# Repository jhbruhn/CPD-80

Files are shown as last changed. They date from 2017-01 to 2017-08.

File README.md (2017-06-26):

# Crazy Programmable Device (CPD)

## (Planned) Features

* 6MHz Z80 Processor
* UART Serial Communication
* 64k RAM
* 32k ROM
* CF Card Support (FAT16 or FAT12)

## Memory layout:
| Address | Type |
| --- | --- |
| 0x0000-0x7FFF | ROM / RAM  |
| 0x8000-0xFFFF | RAM  |

## IO

| A11| A10| A9 | A8 | Device |
| ---|----|----|----|---|
| 0  | 0  | 0  | 0  | IDE Port (CF Card) |
| 0  | 0  | 0  | 1  | UART (16550) |
| 0  | 0  | 1  | 0  | PS/2 Keyboard |
| 0  | 0  | 1  | 1  | RTC-72421 |
| 0  | 1  | 0  | 0  | MemoryBank (write 0 for ROM and 2 for RAM in first 32k) |
| 0  | 1  | 0  | 1  | Video (TMS9918) |
| 0  | 1  | 1  | 0  | Audio (AY-3-8910A) |

To Address device 0:

B = 0

OUT (C), d

To Address device 1:

B = 1

OUT (C), d

etc...

sdcc:
__banked __ad(0x16c) int pedabaumert oder so

##Future:
Video Card with TMS9918. Also PS/2 keyboard input (or something similar). Real time Clock?

## Boot:
* start at 0x0000.
* load Bootsector from CF card to 0x8000, or into BANK RAM at 0x0000.
* jump to 0x8000 (0x0000)
* Bootsector loads FAT files, executes KERNEL.ULF or something like that. Autoexec.

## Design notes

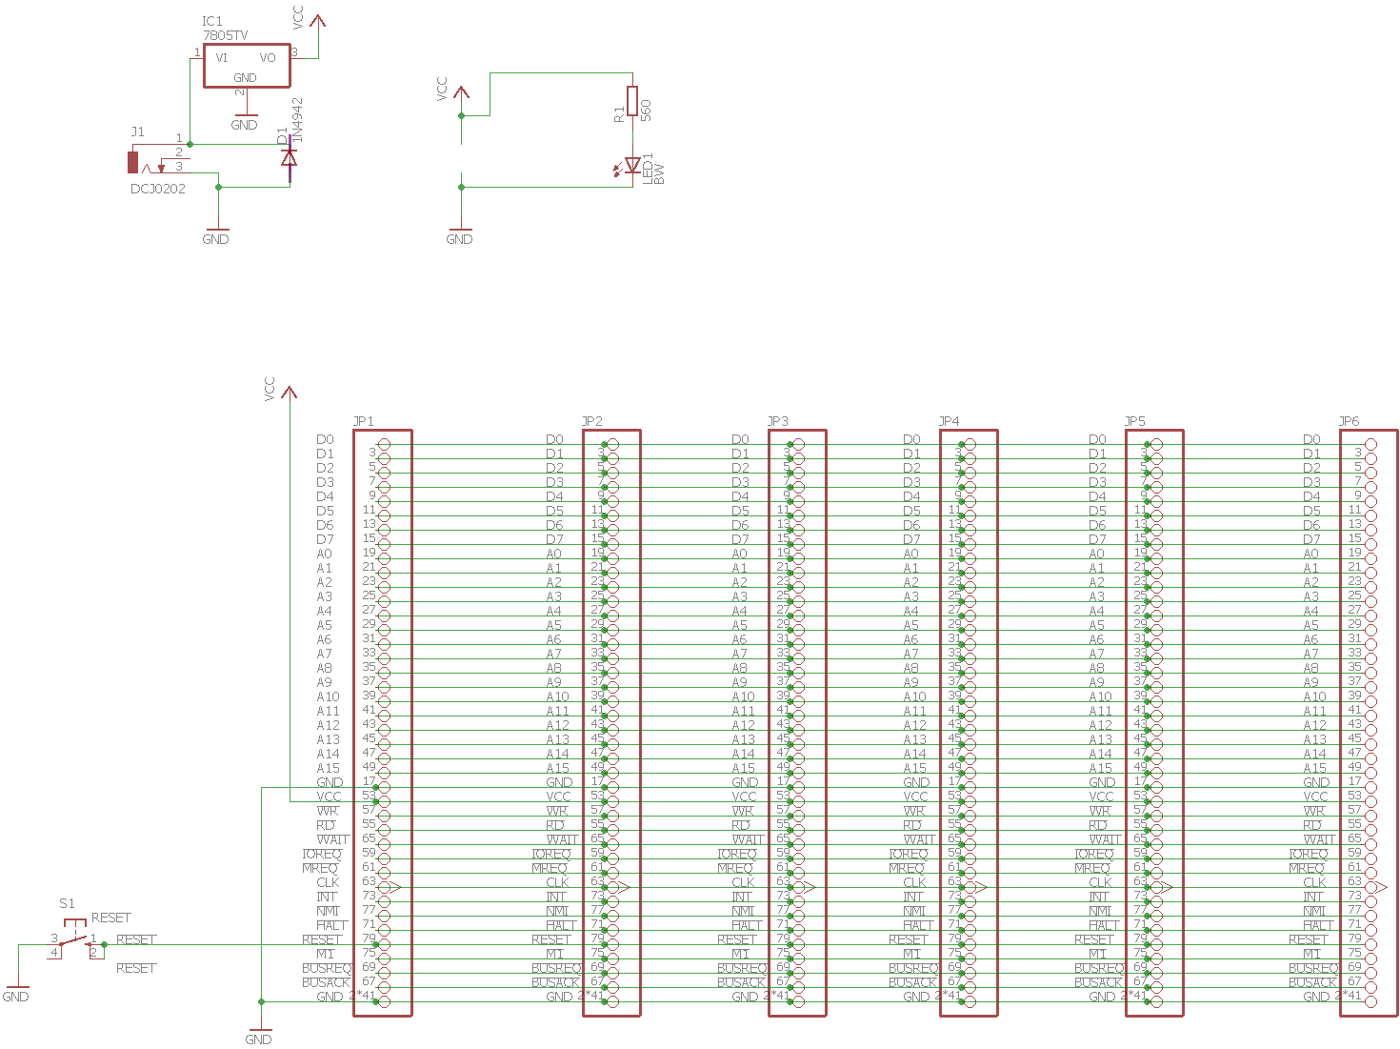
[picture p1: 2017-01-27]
pictures/muddi.png

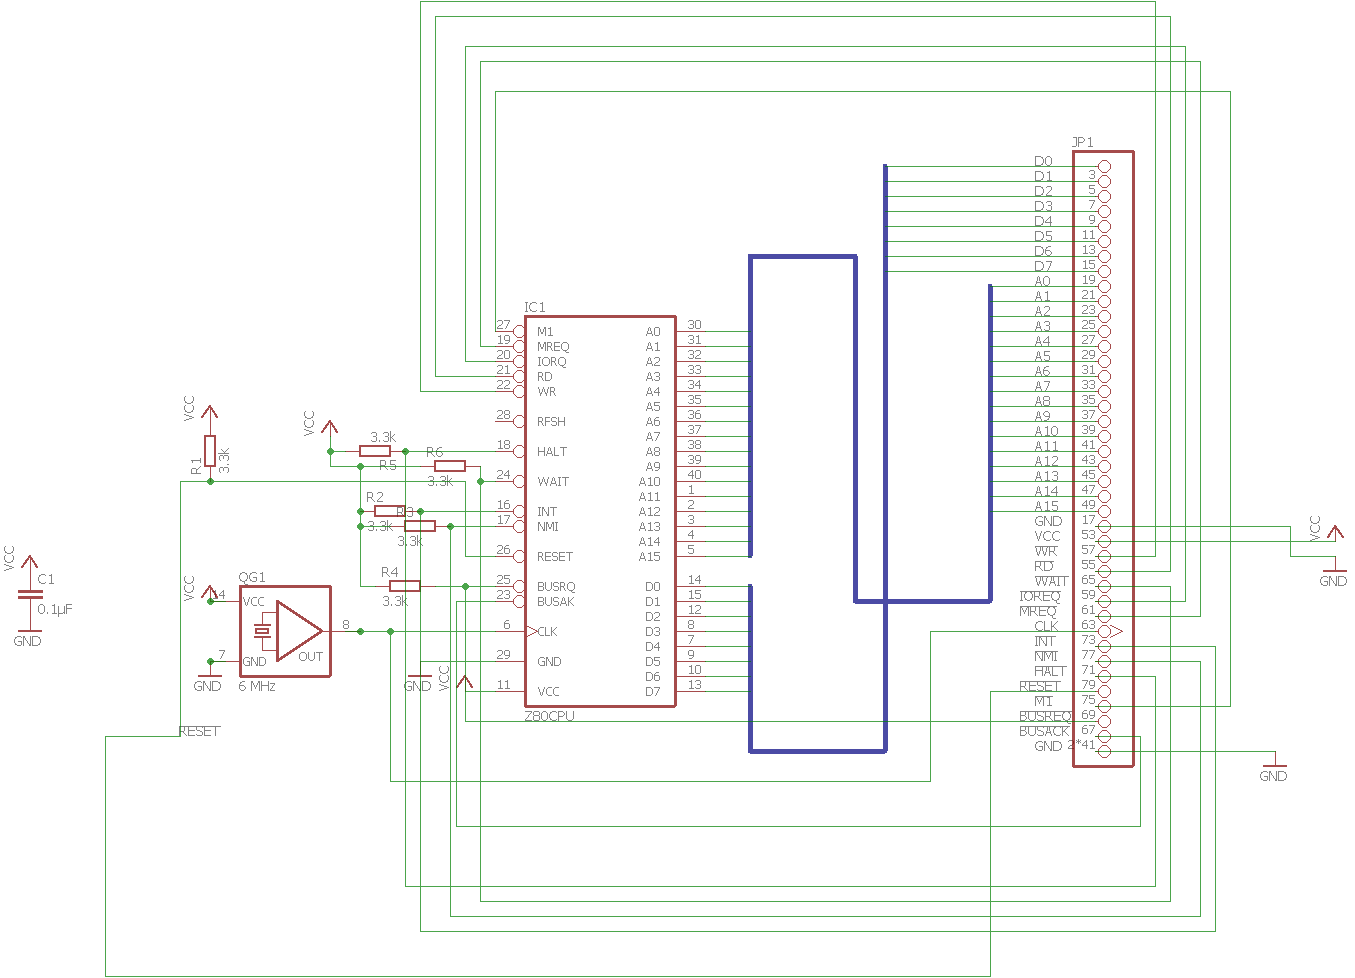
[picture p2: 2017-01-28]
pictures/cpu.png

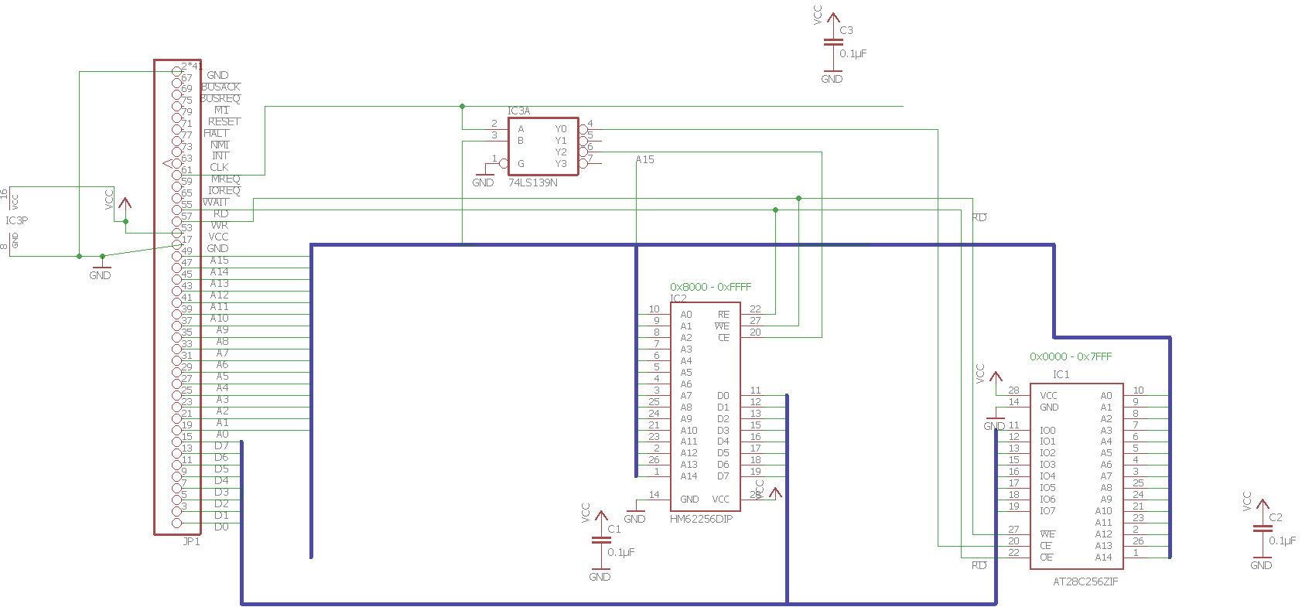
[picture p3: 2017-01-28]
pictures/memory.png

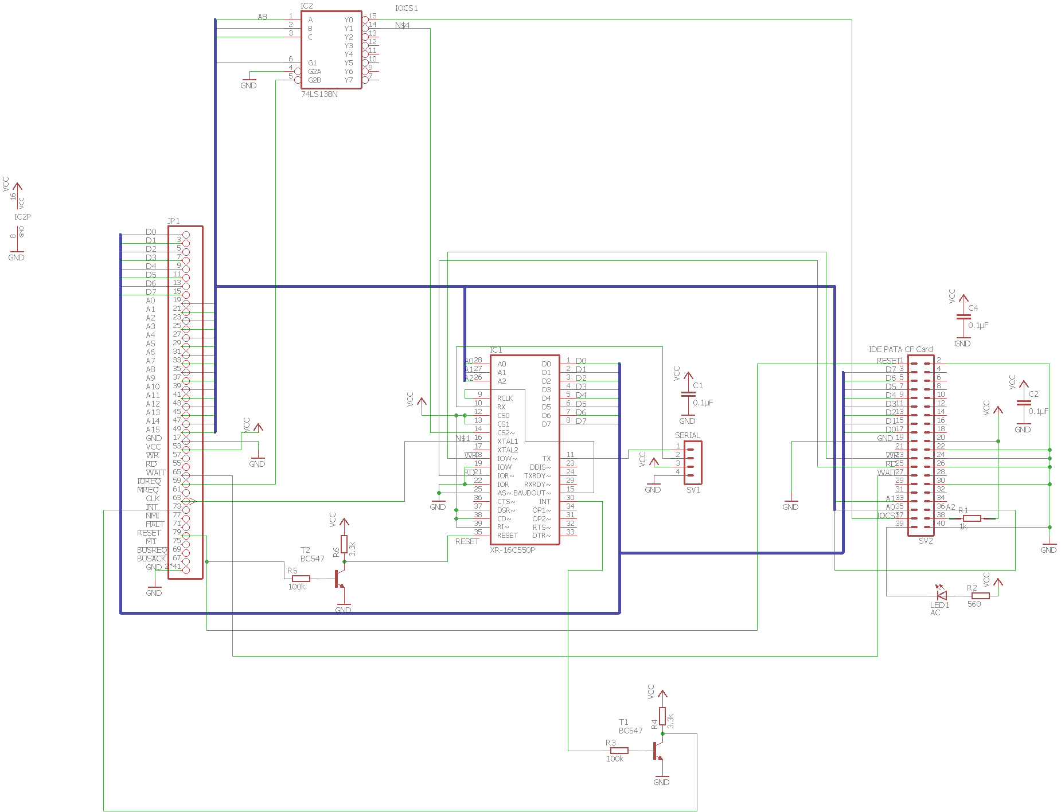
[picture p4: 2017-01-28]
pictures/serialcf.png

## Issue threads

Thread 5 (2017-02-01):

Fix Protection Diode

jhbruhn, 2017-02-01:

Closed 2017-02-01.

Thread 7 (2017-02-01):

Add Oscillator to Serial Board

jhbruhn, 2017-02-01:

Closed 2017-02-02.

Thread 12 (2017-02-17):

Missing VCC/GND Connections

jhbruhn, 2017-02-17:
CPU:
* C1 left to VCC
Memory:
* IC 3 GND (upper left), VCC
* V1 VCC (10)
* C5 VCC (left)
* C6 VCC and GND
SerialCF:
* R1 left to VCC (16c550)
* C4 left to R6 left (VCC)

jhbruhn, 2017-03-03:
Memory
* V2 pin 6 connect to VCC

CFSerial
* IC2 pin 6 connect to VCC

jhbruhn, 2017-06-26:
CPU:
Pin 24 to Wait Resistor
Pin 17 to NMI Resistor
Pin 16 to INT Resistor

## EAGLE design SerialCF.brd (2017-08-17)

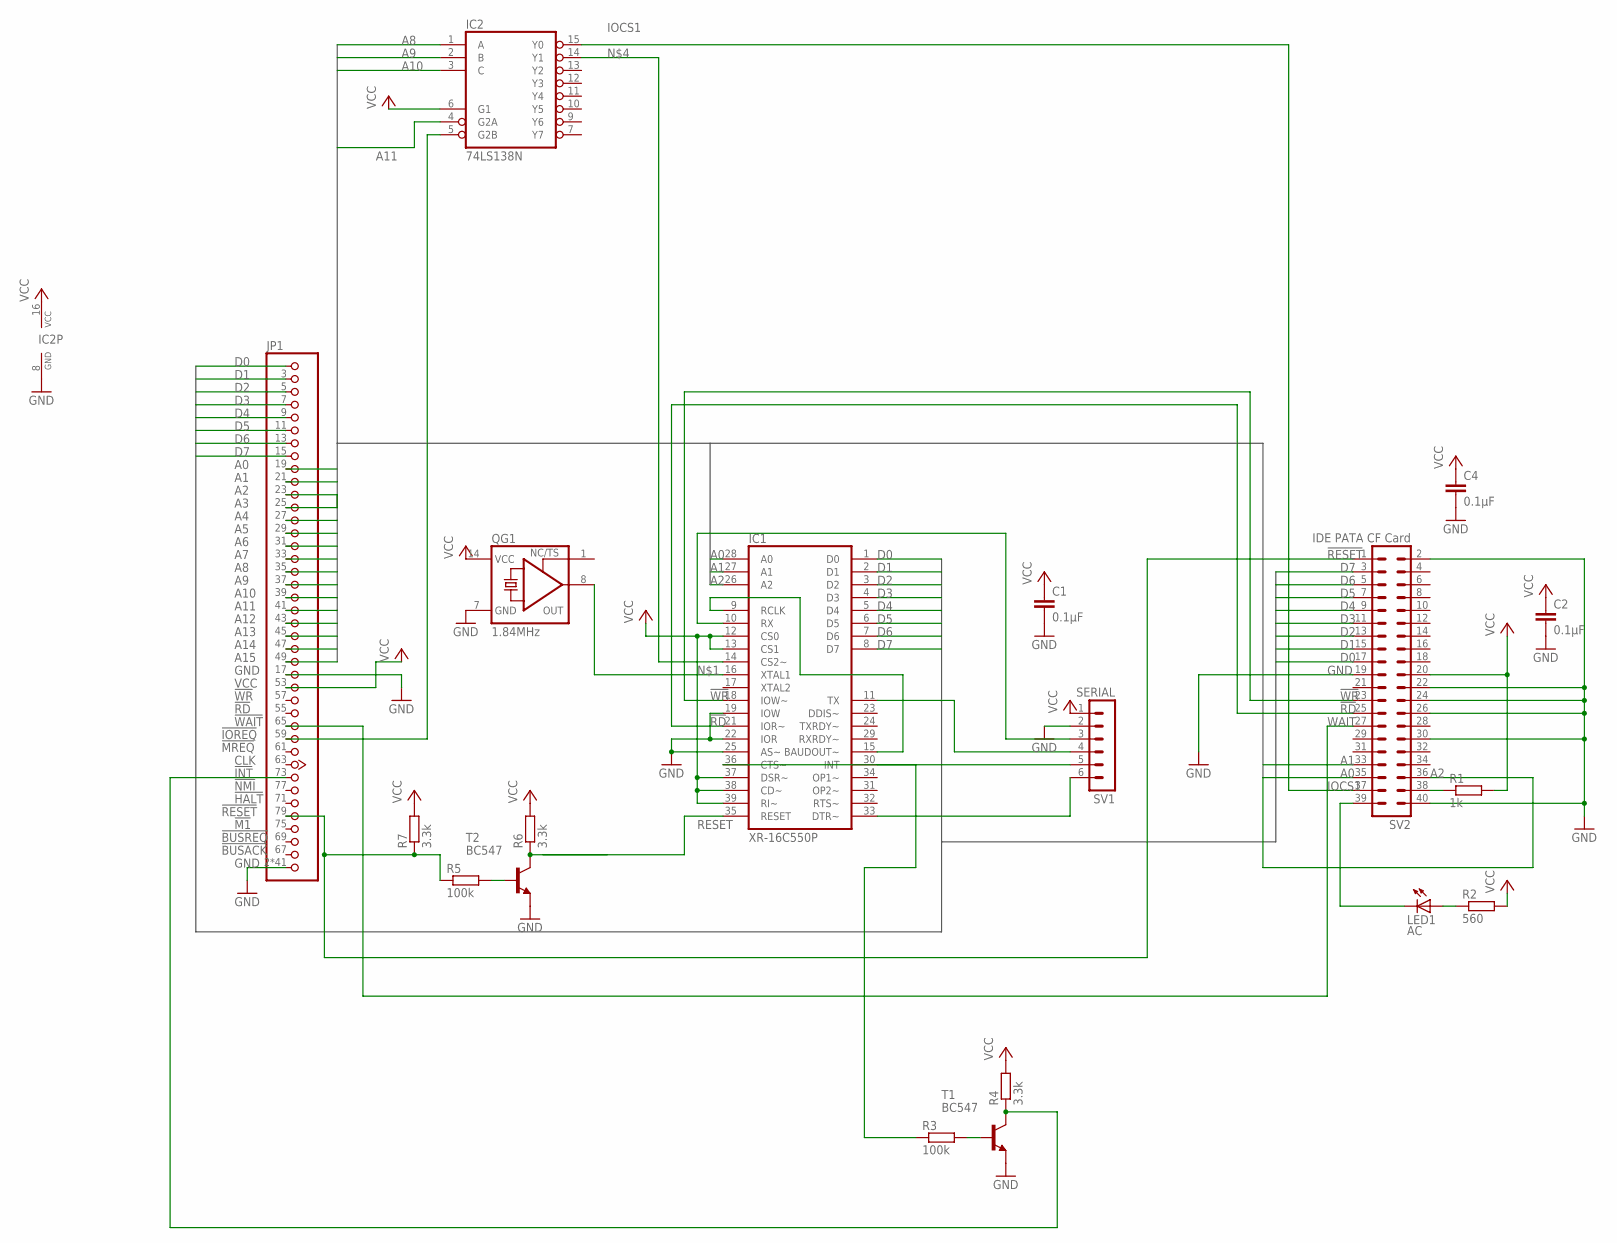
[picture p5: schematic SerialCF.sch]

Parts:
C1, C2, C4: 0.1µF; C5B2.5
IC1: XR-16C550P; DIL40
IC2: 74LS138N; DIL16
JP1: JEANNECTOR/90; 2X25/90
LED1: AC; LED5MM
QG1: 1.84MHz; DIL14S
R1: 1k; 0207/10; MPN MCRE000037
R2: 560; 0204/7
R3, R5: 100k; 0207/2V
R4, R6, R7: 3.3k; 0207/2V
SV1: SERIAL; MA06-1
SV2: IDE PATA CF Card; MA20-2
T1, T2: BC547; TO92

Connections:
!RD: IC1.21 (IOR~), SV2.25
!RESET: JP1.79 (!RESET), R7.1, SV2.1
!WR: IC1.18 (IOW~), SV2.23
A0: IC1.28 (A0), JP1.19 (A0), SV2.35
A1: IC1.27 (A1), JP1.21 (A1), SV2.33
A2: IC1.26 (A2), JP1.23 (A2), SV2.36
A3: JP1.25 (A3)
A4: JP1.27 (A4)
A5: JP1.29 (A5)
A6: JP1.31 (A6)
A7: JP1.33 (A7)
A8: IC2.1 (A), JP1.35 (A8)
A9: IC2.2 (B), JP1.37 (A9)
A10: IC2.3 (C), JP1.39 (A10)
A11: IC2.4 (G2A), JP1.41 (A11)
A12: JP1.43 (A12)
A13: JP1.45 (A13)
A14: JP1.47 (A14)
A15: JP1.49 (A15)
D0: IC1.1 (D0), JP1.1 (D0), SV2.17
D1: IC1.2 (D1), JP1.3 (D1), SV2.15
D2: IC1.3 (D2), JP1.5 (D2), SV2.13
D3: IC1.4 (D3), JP1.7 (D3), SV2.11
D4: IC1.5 (D4), JP1.9 (D4), SV2.9
D5: IC1.6 (D5), JP1.11 (D5), SV2.7
D6: IC1.7 (D6), JP1.13 (D6), SV2.5
D7: IC1.8 (D7), JP1.15 (D7), SV2.3
GND: C1.2, C2.2, C4.2, IC1.19 (IOW), IC1.20 (GND), IC1.22 (IOR), IC1.25 (AS~), IC2.8 (GND), JP1.2 (GND), JP1.4 (GND), JP1.6 (GND), JP1.8 (GND), JP1.10 (GND), JP1.12 (GND), JP1.14 (GND), JP1.16 (GND), JP1.17 (GND), JP1.18 (GND), JP1.20 (GND), JP1.22 (GND), JP1.24 (GND), JP1.26 (GND), JP1.28 (GND), JP1.30 (GND), JP1.32 (GND), JP1.34 (GND), JP1.36 (GND), JP1.38 (GND), JP1.40 (GND), JP1.42 (GND), JP1.44 (GND), JP1.46 (GND), JP1.48 (GND), JP1.50 (GND), JP1.51 (GND), JP1.52 (GND), JP1.54 (GND), JP1.56 (GND), JP1.58 (GND), JP1.60 (GND), JP1.62 (GND), JP1.64 (GND), JP1.66 (GND), JP1.68 (GND), JP1.70 (GND), JP1.72 (GND), JP1.74 (GND), JP1.76 (GND), JP1.78 (GND), JP1.80 (GND), QG1.7 (GND), SV1.2, SV2.2, SV2.19, SV2.22, SV2.24, SV2.26, SV2.30, SV2.40, T1.1 (E), T2.1 (E)
IOCS1: IC2.15 (Y0), SV2.37
unnamed: IC1.16 (XTAL1), QG1.8 (OUT)
unnamed: LED1.K (C), SV2.39
unnamed: LED1.A, R2.1
unnamed: IC1.14 (CS2~), IC2.14 (Y1)
unnamed: IC2.5 (G2B), JP1.59 (!IOREQ)
unnamed: R5.2, T2.2 (B)
unnamed: R6.1, T2.3 (C)
unnamed: R3.2, T1.2 (B)
unnamed: JP1.73 (!INT), R4.1, T1.3 (C)
unnamed: IC1.30 (INT), R3.1
unnamed: IC1.11 (TX), SV1.4
unnamed: IC1.36 (CTS~), SV1.5
unnamed: IC1.9 (RCLK), IC1.15 (BAUDOUT~)
unnamed: IC1.33 (DTR~), SV1.6
unnamed: IC1.10 (RX), SV1.3
unnamed: R1.1, SV2.38
RESET: IC1.35 (RESET)
VCC: C1.1, C2.1, C4.1, IC1.12 (CS0), IC1.13 (CS1), IC1.37 (DSR~), IC1.38 (CD~), IC1.39 (RI~), IC1.40 (VCC), IC2.6 (G1), IC2.16 (VCC), JP1.53 (VCC), QG1.14 (VCC), R1.2, R2.2, R4.2, R6.2, R7.2, SV1.1, SV2.20
WAIT: JP1.65 (!WAIT), SV2.27

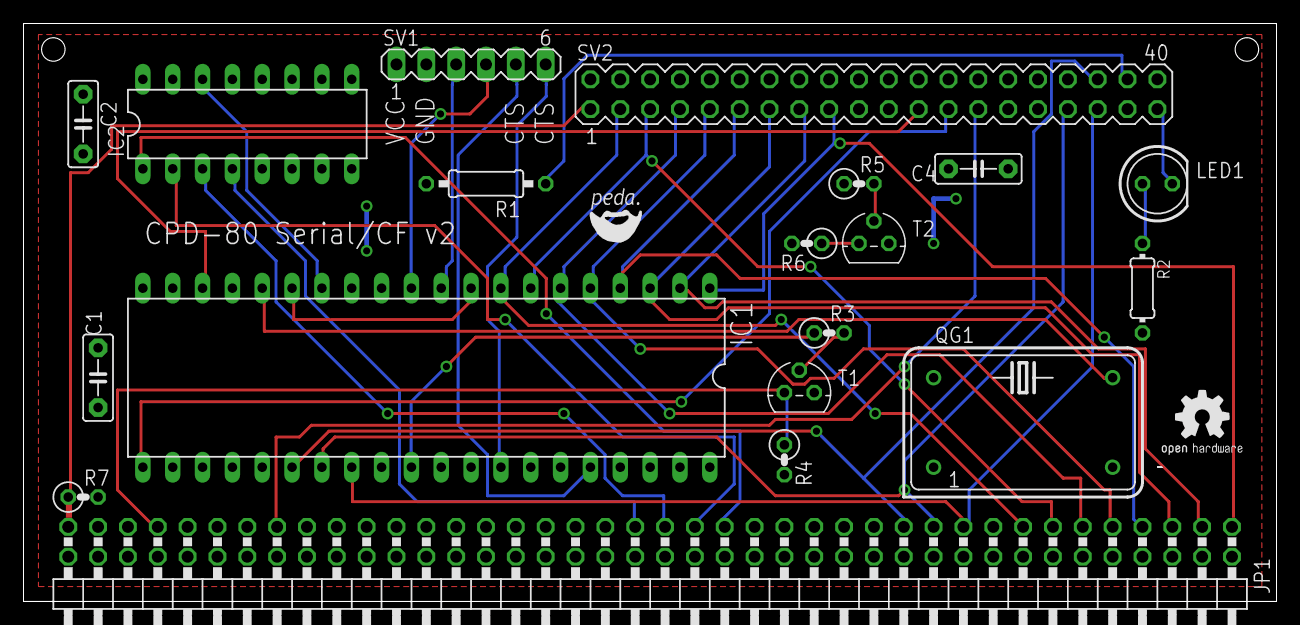
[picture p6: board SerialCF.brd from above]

Board: 2 copper layers, 106.7 x 49.2 mm, 20 parts (0 on the bottom side), 38 nets.

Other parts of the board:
U$1: OSHW2

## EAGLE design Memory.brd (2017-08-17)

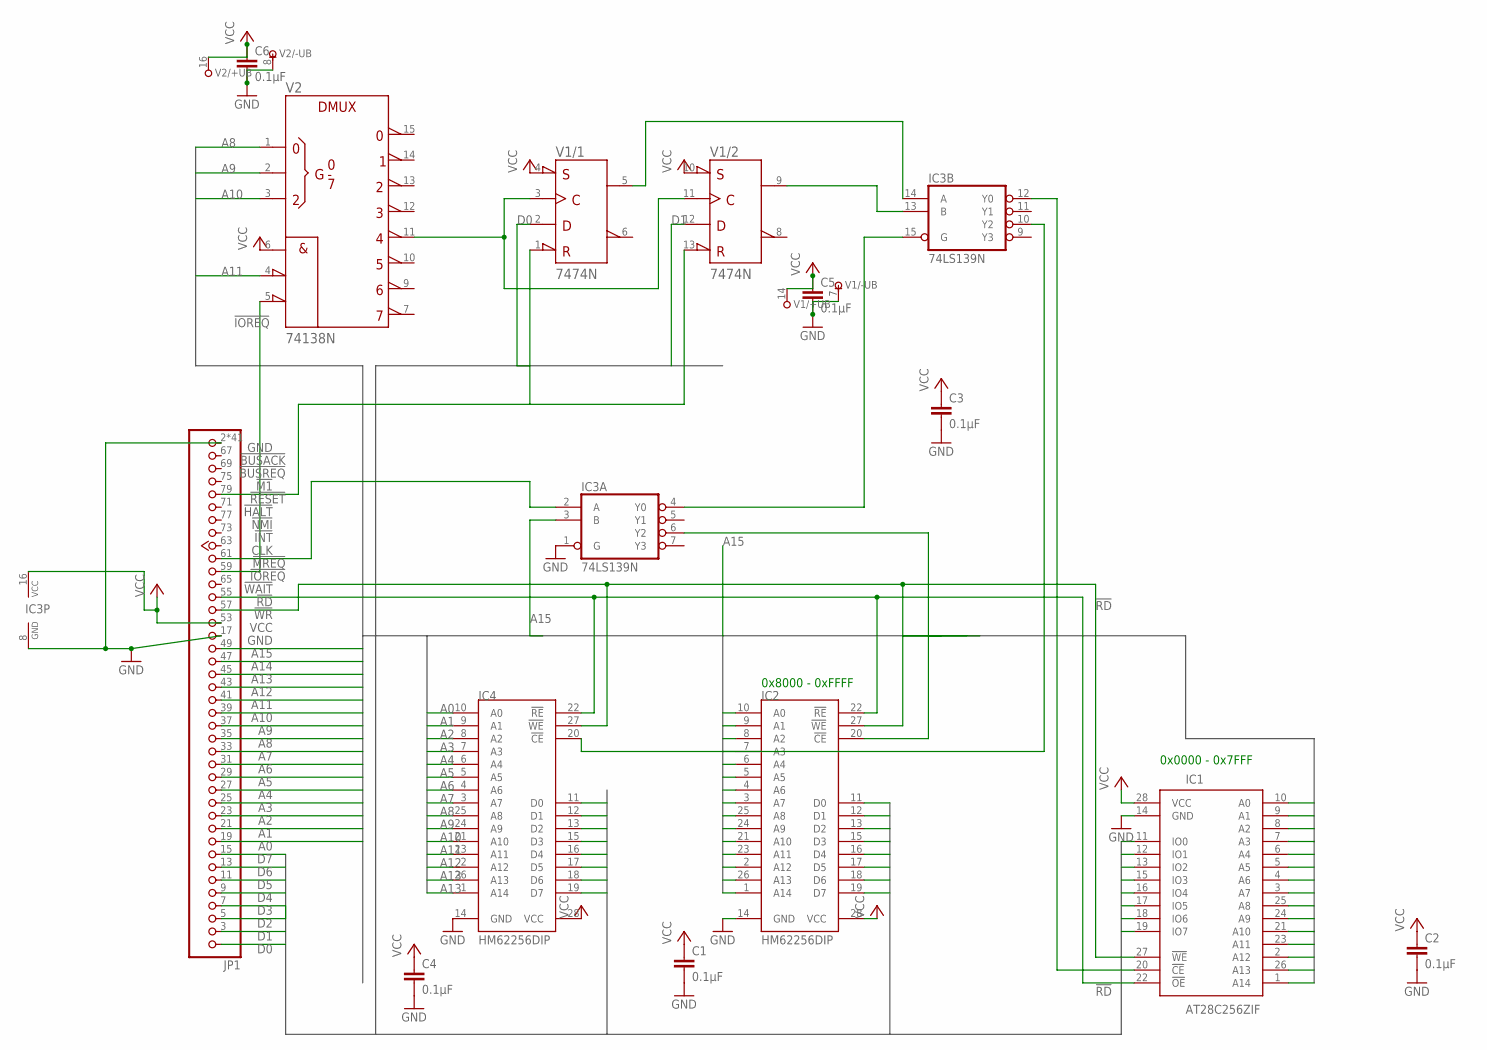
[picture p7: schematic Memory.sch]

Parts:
C1, C2, C3, C4, C5, C6: 0.1µF; C5B2.5
IC1: AT28C256ZIF; DIL28-ZIF
IC2, IC4: HM62256DIP; HM62256-DIP
IC3: 74LS139N; DIL16
JP1: JEANNECTOR/90; 2X25/90
V1: 7474N; DIL14
V2: 74138N; DIL16

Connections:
!IOREQ: JP1.59 (!IOREQ), V2.5 (!G2B)
!MREQ: IC3.2 (A), JP1.61 (!MREQ)
!RD: IC1.22 (!OE), IC2.22 (!RE), IC4.22 (!RE), JP1.55 (!RD)
!WR: IC1.27 (!WE), IC2.27 (!WE), IC4.27 (!WE), JP1.57 (!WR)
A0: IC1.10 (A0), IC2.10 (A0), IC4.10 (A0), JP1.19 (A0)
A1: IC1.9 (A1), IC2.9 (A1), IC4.9 (A1), JP1.21 (A1)
A2: IC1.8 (A2), IC2.8 (A2), IC4.8 (A2), JP1.23 (A2)
A3: IC1.7 (A3), IC2.7 (A3), IC4.7 (A3), JP1.25 (A3)
A4: IC1.6 (A4), IC2.6 (A4), IC4.6 (A4), JP1.27 (A4)
A5: IC1.5 (A5), IC2.5 (A5), IC4.5 (A5), JP1.29 (A5)
A6: IC1.4 (A6), IC2.4 (A6), IC4.4 (A6), JP1.31 (A6)
A7: IC1.3 (A7), IC2.3 (A7), IC4.3 (A7), JP1.33 (A7)
A8: IC1.25 (A8), IC2.25 (A8), IC4.25 (A8), JP1.35 (A8), V2.1 (A)
A9: IC1.24 (A9), IC2.24 (A9), IC4.24 (A9), JP1.37 (A9), V2.2 (B)
A10: IC1.21 (A10), IC2.21 (A10), IC4.21 (A10), JP1.39 (A10), V2.3 (C)
A11: IC1.23 (A11), IC2.23 (A11), IC4.23 (A11), JP1.41 (A11), V2.4 (!G2A)
A12: IC1.2 (A12), IC2.2 (A12), IC4.2 (A12), JP1.43 (A12)
A13: IC1.26 (A13), IC2.26 (A13), IC4.26 (A13), JP1.45 (A13)
A14: IC1.1 (A14), IC2.1 (A14), IC4.1 (A14), JP1.47 (A14)
A15: IC3.3 (B), JP1.49 (A15)
D0: IC1.11 (IO0), IC2.11 (D0), IC4.11 (D0), JP1.1 (D0), V1.2 (D)
D1: IC1.12 (IO1), IC2.12 (D1), IC4.12 (D1), JP1.3 (D1), V1.12 (D)
D2: IC1.13 (IO2), IC2.13 (D2), IC4.13 (D2), JP1.5 (D2)
D3: IC1.15 (IO3), IC2.15 (D3), IC4.15 (D3), JP1.7 (D3)
D4: IC1.16 (IO4), IC2.16 (D4), IC4.16 (D4), JP1.9 (D4)
D5: IC1.17 (IO5), IC2.17 (D5), IC4.17 (D5), JP1.11 (D5)
D6: IC1.18 (IO6), IC2.18 (D6), IC4.18 (D6), JP1.13 (D6)
D7: IC1.19 (IO7), IC2.19 (D7), IC4.19 (D7), JP1.15 (D7)
GND: C1.2, C2.2, C3.2, C4.2, C5.2, C6.2, IC1.14 (GND), IC2.14 (GND), IC3.1 (G), IC3.8 (GND), IC4.14 (GND), JP1.2 (GND), JP1.4 (GND), JP1.6 (GND), JP1.8 (GND), JP1.10 (GND), JP1.12 (GND), JP1.14 (GND), JP1.16 (GND), JP1.17 (GND), JP1.18 (GND), JP1.20 (GND), JP1.22 (GND), JP1.24 (GND), JP1.26 (GND), JP1.28 (GND), JP1.30 (GND), JP1.32 (GND), JP1.34 (GND), JP1.36 (GND), JP1.38 (GND), JP1.40 (GND), JP1.42 (GND), JP1.44 (GND), JP1.46 (GND), JP1.48 (GND), JP1.50 (GND), JP1.51 (GND), JP1.52 (GND), JP1.54 (GND), JP1.56 (GND), JP1.58 (GND), JP1.60 (GND), JP1.62 (GND), JP1.64 (GND), JP1.66 (GND), JP1.68 (GND), JP1.70 (GND), JP1.72 (GND), JP1.74 (GND), JP1.76 (GND), JP1.78 (GND), JP1.80 (GND), V1.7 (-UB), V2.8 (-UB)
unnamed: IC2.20 (!CE), IC3.6 (Y2)
unnamed: IC1.20 (!CE), IC3.12 (Y0)
unnamed: IC3.14 (A), V1.5 (Q)
unnamed: V1.3 (CLK), V1.11 (CLK), V2.11 (Y4)
unnamed: IC3.13 (B), V1.9 (Q)
unnamed: JP1.79 (!RESET), V1.1 (!CLR), V1.13 (!CLR)
unnamed: IC3.4 (Y0), IC3.15 (G)
unnamed: IC3.10 (Y2), IC4.20 (!CE)
VCC: C1.1, C2.1, C3.1, C4.1, C5.1, C6.1, IC1.28 (VCC), IC2.28 (VCC), IC3.16 (VCC), IC4.28 (VCC), JP1.53 (VCC), V1.4 (!PRE), V1.10 (!PRE), V1.14 (+UB), V2.6 (G1), V2.16 (+UB)

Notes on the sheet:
0x0000 - 0x7FFF
0x8000 - 0xFFFF

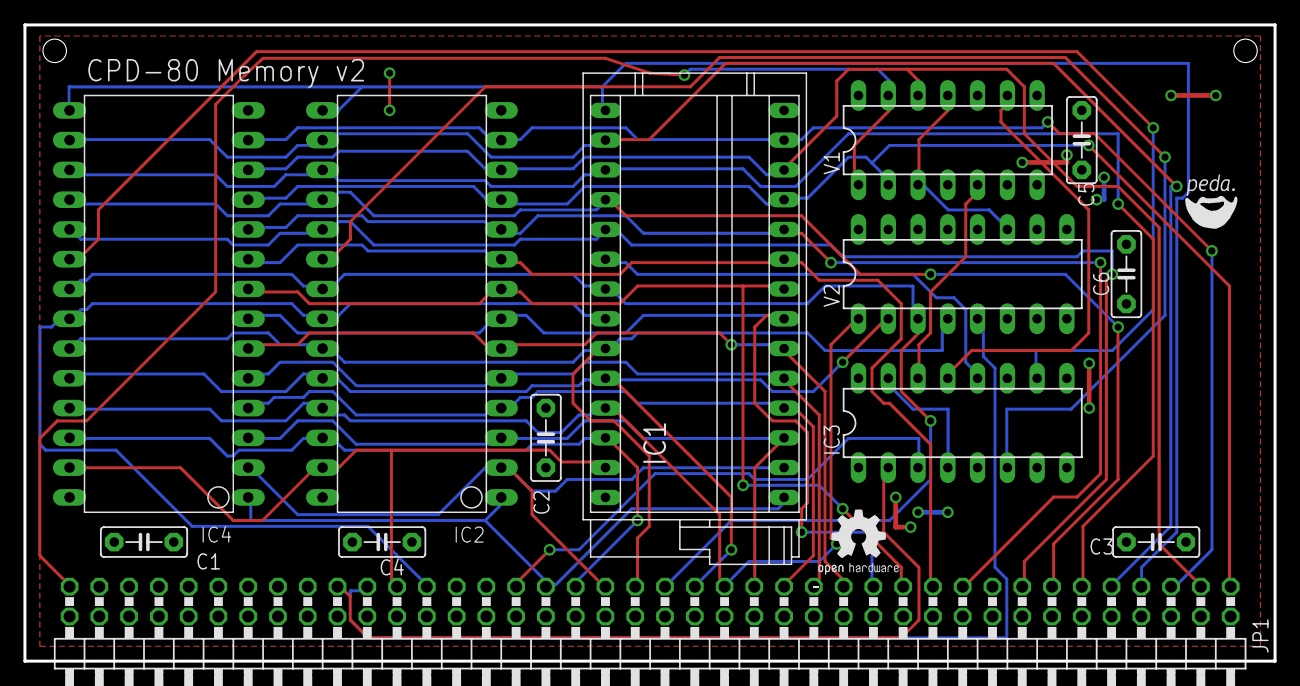
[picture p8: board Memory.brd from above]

Board: 2 copper layers, 106.7 x 54.3 mm, 14 parts (0 on the bottom side), 38 nets.

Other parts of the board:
U$1: OSHW2

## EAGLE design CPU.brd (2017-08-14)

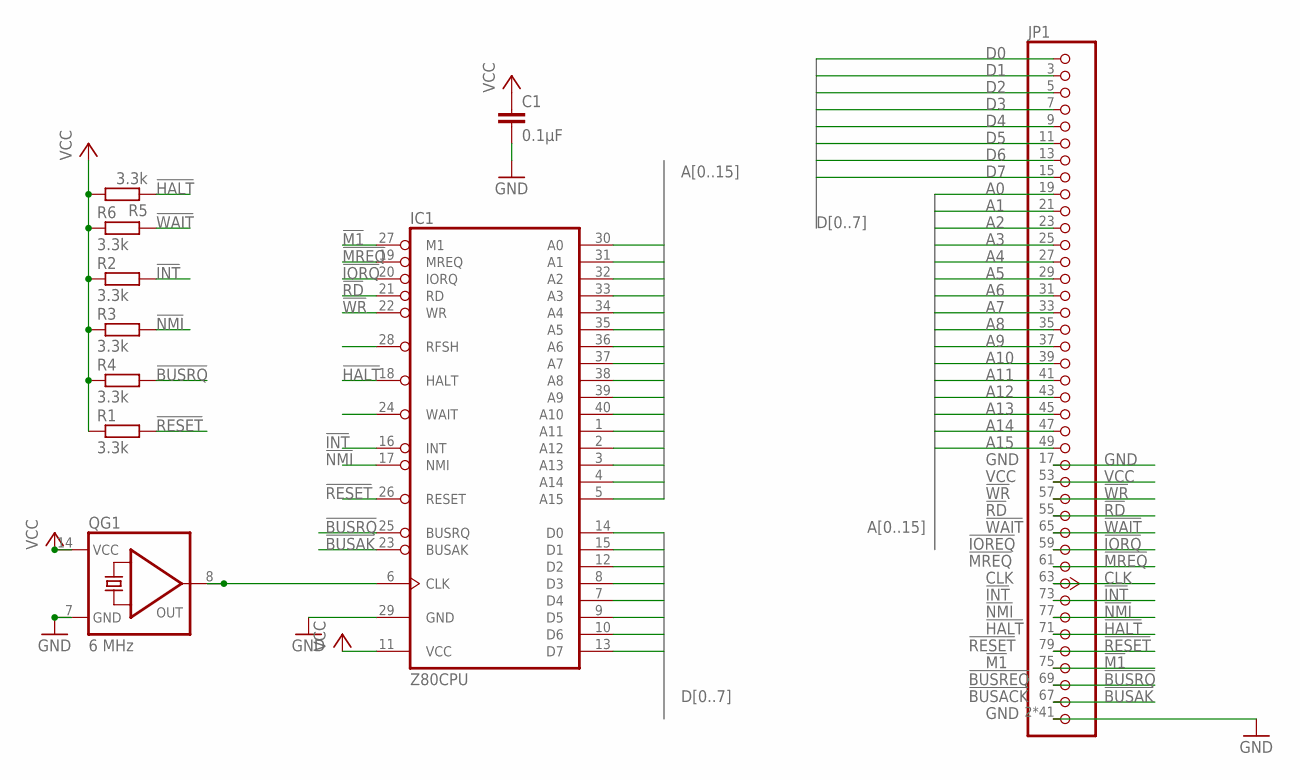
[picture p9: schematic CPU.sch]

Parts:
C1: 0.1µF; C5B2.5
IC1: Z80CPU; DIL40
JP1: JEANNECTOR/90; 2X25/90
QG1: 6 MHz; DIL14S
R1, R2, R3, R4, R5, R6: 3.3k; 0207/2V

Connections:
!BUSAK: IC1.23 (BUSAK), JP1.67 (!BUSACK)
!BUSRQ: IC1.25 (BUSRQ), JP1.69 (!BUSRQ), R4.2
!HALT: IC1.18 (HALT), JP1.71 (!HALT), R5.1
!INT: IC1.16 (INT), JP1.73 (!INT), R2.2
!IORQ: IC1.20 (IORQ), JP1.59 (!IOREQ)
!M1: IC1.27 (M1), JP1.75 (!M1)
!MREQ: IC1.19 (MREQ), JP1.61 (!MREQ)
!NMI: IC1.17 (NMI), JP1.77 (!NMI), R3.2
!RD: IC1.21 (RD), JP1.55 (!RD)
!RESET: IC1.26 (RESET), JP1.79 (!RESET), R1.2
!RFSH: IC1.28 (RFSH)
!WAIT: IC1.24 (WAIT), JP1.65 (!WAIT), R6.2
!WR: IC1.22 (WR), JP1.57 (!WR)
A0: IC1.30 (A0), JP1.19 (A0)
A1: IC1.31 (A1), JP1.21 (A1)
A2: IC1.32 (A2), JP1.23 (A2)
A3: IC1.33 (A3), JP1.25 (A3)
A4: IC1.34 (A4), JP1.27 (A4)
A5: IC1.35 (A5), JP1.29 (A5)
A6: IC1.36 (A6), JP1.31 (A6)
A7: IC1.37 (A7), JP1.33 (A7)
A8: IC1.38 (A8), JP1.35 (A8)
A9: IC1.39 (A9), JP1.37 (A9)
A10: IC1.40 (A10), JP1.39 (A10)
A11: IC1.1 (A11), JP1.41 (A11)
A12: IC1.2 (A12), JP1.43 (A12)
A13: IC1.3 (A13), JP1.45 (A13)
A14: IC1.4 (A14), JP1.47 (A14)
A15: IC1.5 (A15), JP1.49 (A15)
CLK: IC1.6 (CLK), JP1.63 (CLK), QG1.8 (OUT)
D0: IC1.14 (D0), JP1.1 (D0)
D1: IC1.15 (D1), JP1.3 (D1)
D2: IC1.12 (D2), JP1.5 (D2)
D3: IC1.8 (D3), JP1.7 (D3)
D4: IC1.7 (D4), JP1.9 (D4)
D5: IC1.9 (D5), JP1.11 (D5)
D6: IC1.10 (D6), JP1.13 (D6)
D7: IC1.13 (D7), JP1.15 (D7)
GND: C1.2, IC1.29 (GND), JP1.2 (GND), JP1.4 (GND), JP1.6 (GND), JP1.8 (GND), JP1.10 (GND), JP1.12 (GND), JP1.14 (GND), JP1.16 (GND), JP1.17 (GND), JP1.18 (GND), JP1.20 (GND), JP1.22 (GND), JP1.24 (GND), JP1.26 (GND), JP1.28 (GND), JP1.30 (GND), JP1.32 (GND), JP1.34 (GND), JP1.36 (GND), JP1.38 (GND), JP1.40 (GND), JP1.42 (GND), JP1.44 (GND), JP1.46 (GND), JP1.48 (GND), JP1.50 (GND), JP1.51 (GND), JP1.52 (GND), JP1.54 (GND), JP1.56 (GND), JP1.58 (GND), JP1.60 (GND), JP1.62 (GND), JP1.64 (GND), JP1.66 (GND), JP1.68 (GND), JP1.70 (GND), JP1.72 (GND), JP1.74 (GND), JP1.76 (GND), JP1.78 (GND), JP1.80 (GND), QG1.7 (GND)
VCC: C1.1, IC1.11 (VCC), JP1.53 (VCC), QG1.14 (VCC), R1.1, R2.1, R3.1, R4.1, R5.2, R6.1

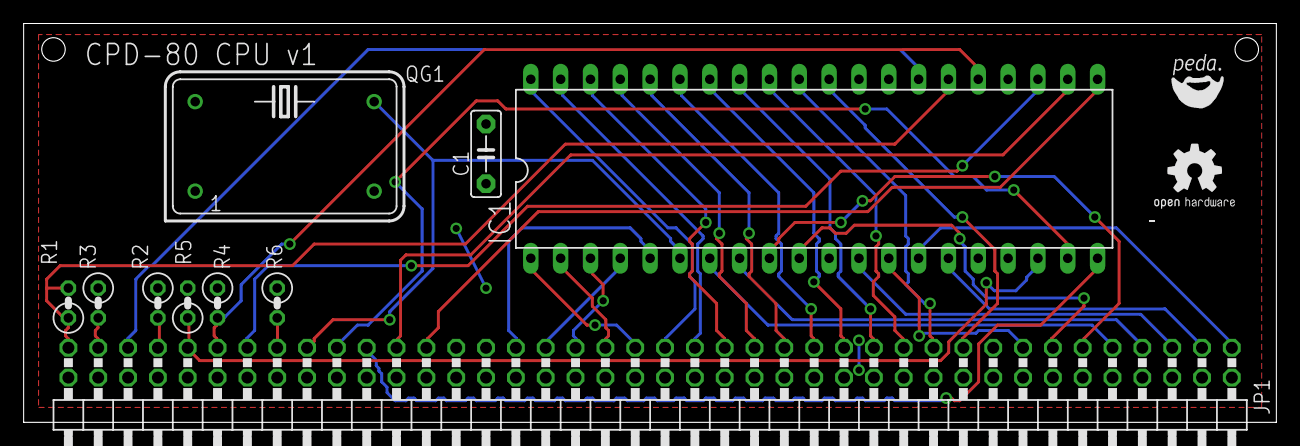
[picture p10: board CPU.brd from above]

Board: 2 copper layers, 106.7 x 33.9 mm, 11 parts (0 on the bottom side), 39 nets.

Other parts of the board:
U$1: OSHW2

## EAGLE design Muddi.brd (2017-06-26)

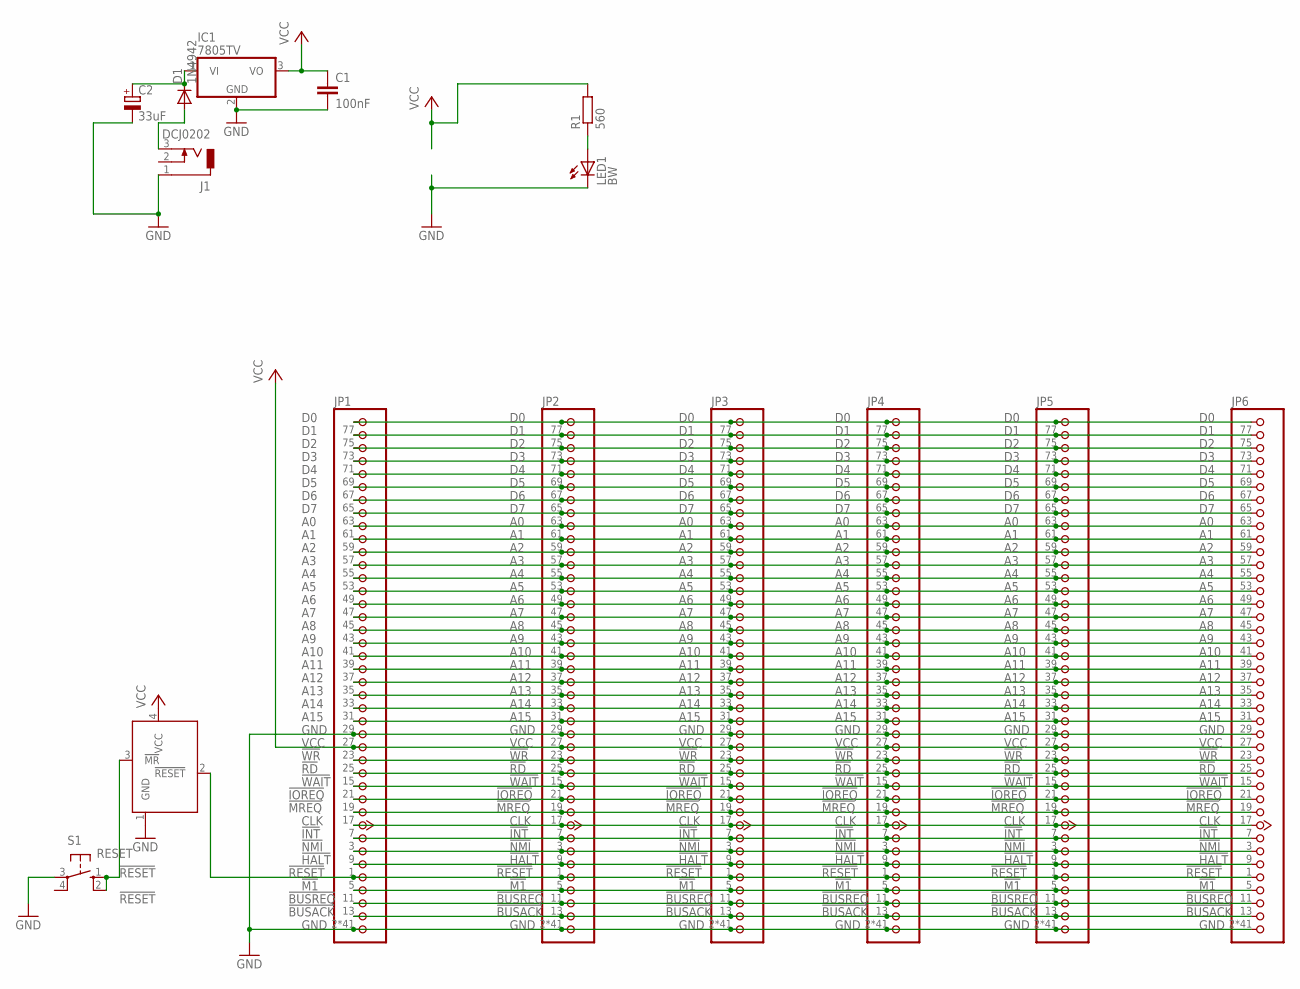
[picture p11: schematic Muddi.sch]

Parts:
C1: 100nF; C2.5-2
C2: 33uF; E2,5-7
D1: 1N4942; DO41-10; MPN 1N4935G
IC1: 7805TV; TO220V
J1: DCJ0202
JP1, JP2, JP3, JP4, JP5, JP6: JEANNECTOR_57102-F08-25; 57102-F08-25
LED1: BW; LED5MM
MAX811: MAX811; SOT143
R1: 560; 0207/2V
S1: RESET; B3F-10XX

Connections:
!BUSACK: JP1.13 (!BUSACK), JP2.13 (!BUSACK), JP3.13 (!BUSACK), JP4.13 (!BUSACK), JP5.13 (!BUSACK), JP6.13 (!BUSACK)
!BUSREQ: JP1.11 (!BUSRQ), JP2.11 (!BUSRQ), JP3.11 (!BUSRQ), JP4.11 (!BUSRQ), JP5.11 (!BUSRQ), JP6.11 (!BUSRQ)
!HALT: JP1.9 (!HALT), JP2.9 (!HALT), JP3.9 (!HALT), JP4.9 (!HALT), JP5.9 (!HALT), JP6.9 (!HALT)
!INT: JP1.7 (!INT), JP2.7 (!INT), JP3.7 (!INT), JP4.7 (!INT), JP5.7 (!INT), JP6.7 (!INT)
!IOREQ: JP1.21 (!IOREQ), JP2.21 (!IOREQ), JP3.21 (!IOREQ), JP4.21 (!IOREQ), JP5.21 (!IOREQ), JP6.21 (!IOREQ)
!M1: JP1.5 (!M1), JP2.5 (!M1), JP3.5 (!M1), JP4.5 (!M1), JP5.5 (!M1), JP6.5 (!M1)
!MREQ: JP1.19 (!MREQ), JP2.19 (!MREQ), JP3.19 (!MREQ), JP4.19 (!MREQ), JP5.19 (!MREQ), JP6.19 (!MREQ)
!NMI: JP1.3 (!NMI), JP2.3 (!NMI), JP3.3 (!NMI), JP4.3 (!NMI), JP5.3 (!NMI), JP6.3 (!NMI)
!RD: JP1.25 (!RD), JP2.25 (!RD), JP3.25 (!RD), JP4.25 (!RD), JP5.25 (!RD), JP6.25 (!RD)
!RESE: JP1.1 (!RESET), JP2.1 (!RESET), JP3.1 (!RESET), JP4.1 (!RESET), JP5.1 (!RESET), JP6.1 (!RESET), MAX811.2 (!RESET)
!WAIT: JP1.15 (!WAIT), JP2.15 (!WAIT), JP3.15 (!WAIT), JP4.15 (!WAIT), JP5.15 (!WAIT), JP6.15 (!WAIT)
!WR: JP1.23 (!WR), JP2.23 (!WR), JP3.23 (!WR), JP4.23 (!WR), JP5.23 (!WR), JP6.23 (!WR)
A0: JP1.63 (A0), JP2.63 (A0), JP3.63 (A0), JP4.63 (A0), JP5.63 (A0), JP6.63 (A0)
A15: JP1.31 (A15), JP2.31 (A15), JP3.31 (A15), JP4.31 (A15), JP5.31 (A15), JP6.31 (A15)
CLK: JP1.17 (CLK), JP2.17 (CLK), JP3.17 (CLK), JP4.17 (CLK), JP5.17 (CLK), JP6.17 (CLK)
D0: JP1.79 (D0), JP2.79 (D0), JP3.79 (D0), JP4.79 (D0), JP5.79 (D0), JP6.79 (D0)
D7: JP1.65 (D7), JP2.65 (D7), JP3.65 (D7), JP4.65 (D7), JP5.65 (D7), JP6.65 (D7)
GND: C1.2, C2.-, IC1.2 (GND), J1.1, JP1.2 (GND), JP1.4 (GND), JP1.6 (GND), JP1.8 (GND), JP1.10 (GND), JP1.12 (GND), JP1.14 (GND), JP1.16 (GND), JP1.18 (GND), JP1.20 (GND), JP1.22 (GND), JP1.24 (GND), JP1.26 (GND), JP1.28 (GND), JP1.29 (GND), JP1.30 (GND), JP1.32 (GND), JP1.34 (GND), JP1.36 (GND), JP1.38 (GND), JP1.40 (GND), JP1.42 (GND), JP1.44 (GND), JP1.46 (GND), JP1.48 (GND), JP1.50 (GND), JP1.51 (GND), JP1.52 (GND), JP1.54 (GND), JP1.56 (GND), JP1.58 (GND), JP1.60 (GND), JP1.62 (GND), JP1.64 (GND), JP1.66 (GND), JP1.68 (GND), JP1.70 (GND), JP1.72 (GND), JP1.74 (GND), JP1.76 (GND), JP1.78 (GND), JP1.80 (GND), JP2.2 (GND), JP2.4 (GND), JP2.6 (GND), JP2.8 (GND), JP2.10 (GND), JP2.12 (GND), JP2.14 (GND), JP2.16 (GND), JP2.18 (GND), JP2.20 (GND), JP2.22 (GND), JP2.24 (GND), JP2.26 (GND), JP2.28 (GND), JP2.29 (GND), JP2.30 (GND), JP2.32 (GND), JP2.34 (GND), JP2.36 (GND), JP2.38 (GND), JP2.40 (GND), JP2.42 (GND), JP2.44 (GND), JP2.46 (GND), JP2.48 (GND), JP2.50 (GND), JP2.51 (GND), JP2.52 (GND), JP2.54 (GND), JP2.56 (GND), JP2.58 (GND), JP2.60 (GND), JP2.62 (GND), JP2.64 (GND), JP2.66 (GND), JP2.68 (GND), JP2.70 (GND), JP2.72 (GND), JP2.74 (GND), JP2.76 (GND), JP2.78 (GND), JP2.80 (GND), JP3.2 (GND), JP3.4 (GND), JP3.6 (GND), JP3.8 (GND), JP3.10 (GND), JP3.12 (GND), JP3.14 (GND), JP3.16 (GND), JP3.18 (GND), JP3.20 (GND), JP3.22 (GND), JP3.24 (GND), JP3.26 (GND), JP3.28 (GND), JP3.29 (GND), JP3.30 (GND), JP3.32 (GND), JP3.34 (GND), JP3.36 (GND), JP3.38 (GND), JP3.40 (GND), JP3.42 (GND), JP3.44 (GND), JP3.46 (GND), JP3.48 (GND), JP3.50 (GND), JP3.51 (GND), JP3.52 (GND), JP3.54 (GND), JP3.56 (GND), JP3.58 (GND), JP3.60 (GND), JP3.62 (GND), JP3.64 (GND), JP3.66 (GND), JP3.68 (GND), JP3.70 (GND), JP3.72 (GND), JP3.74 (GND), JP3.76 (GND), JP3.78 (GND), JP3.80 (GND), JP4.2 (GND), JP4.4 (GND), JP4.6 (GND), JP4.8 (GND), JP4.10 (GND), JP4.12 (GND), JP4.14 (GND), JP4.16 (GND), JP4.18 (GND), JP4.20 (GND), JP4.22 (GND), JP4.24 (GND), JP4.26 (GND), JP4.28 (GND), JP4.29 (GND), JP4.30 (GND), JP4.32 (GND), JP4.34 (GND), JP4.36 (GND), JP4.38 (GND), JP4.40 (GND), JP4.42 (GND), JP4.44 (GND), JP4.46 (GND), JP4.48 (GND), JP4.50 (GND), JP4.51 (GND), JP4.52 (GND), JP4.54 (GND), JP4.56 (GND), JP4.58 (GND), JP4.60 (GND), JP4.62 (GND), JP4.64 (GND), JP4.66 (GND), JP4.68 (GND), JP4.70 (GND), JP4.72 (GND), JP4.74 (GND), JP4.76 (GND), JP4.78 (GND), JP4.80 (GND), JP5.2 (GND), JP5.4 (GND), JP5.6 (GND), JP5.8 (GND), JP5.10 (GND), JP5.12 (GND), JP5.14 (GND), JP5.16 (GND), JP5.18 (GND), JP5.20 (GND), JP5.22 (GND), JP5.24 (GND), JP5.26 (GND), JP5.28 (GND), JP5.29 (GND), JP5.30 (GND), JP5.32 (GND), JP5.34 (GND), JP5.36 (GND), JP5.38 (GND), JP5.40 (GND), JP5.42 (GND), JP5.44 (GND), JP5.46 (GND), JP5.48 (GND), JP5.50 (GND), JP5.51 (GND), JP5.52 (GND), JP5.54 (GND), JP5.56 (GND), JP5.58 (GND), JP5.60 (GND), JP5.62 (GND), JP5.64 (GND), JP5.66 (GND), JP5.68 (GND), JP5.70 (GND), JP5.72 (GND), JP5.74 (GND), JP5.76 (GND), JP5.78 (GND), JP5.80 (GND), JP6.2 (GND), JP6.4 (GND), JP6.6 (GND), JP6.8 (GND), JP6.10 (GND), JP6.12 (GND), JP6.14 (GND), JP6.16 (GND), JP6.18 (GND), JP6.20 (GND), JP6.22 (GND), JP6.24 (GND), JP6.26 (GND), JP6.28 (GND), JP6.29 (GND), JP6.30 (GND), JP6.32 (GND), JP6.34 (GND), JP6.36 (GND), JP6.38 (GND), JP6.40 (GND), JP6.42 (GND), JP6.44 (GND), JP6.46 (GND), JP6.48 (GND), JP6.50 (GND), JP6.51 (GND), JP6.52 (GND), JP6.54 (GND), JP6.56 (GND), JP6.58 (GND), JP6.60 (GND), JP6.62 (GND), JP6.64 (GND), JP6.66 (GND), JP6.68 (GND), JP6.70 (GND), JP6.72 (GND), JP6.74 (GND), JP6.76 (GND), JP6.78 (GND), JP6.80 (GND), LED1.K (C), MAX811.1 (GND), S1.3
unnamed: D1.A, J1.3
unnamed: JP1.77 (D1), JP2.77 (D1), JP3.77 (D1), JP4.77 (D1), JP5.77 (D1), JP6.77 (D1)
unnamed: JP1.75 (D2), JP2.75 (D2), JP3.75 (D2), JP4.75 (D2), JP5.75 (D2), JP6.75 (D2)
unnamed: JP1.73 (D3), JP2.73 (D3), JP3.73 (D3), JP4.73 (D3), JP5.73 (D3), JP6.73 (D3)
unnamed: JP1.71 (D4), JP2.71 (D4), JP3.71 (D4), JP4.71 (D4), JP5.71 (D4), JP6.71 (D4)
unnamed: JP1.69 (D5), JP2.69 (D5), JP3.69 (D5), JP4.69 (D5), JP5.69 (D5), JP6.69 (D5)
unnamed: JP1.67 (D6), JP2.67 (D6), JP3.67 (D6), JP4.67 (D6), JP5.67 (D6), JP6.67 (D6)
unnamed: JP1.61 (A1), JP2.61 (A1), JP3.61 (A1), JP4.61 (A1), JP5.61 (A1), JP6.61 (A1)
unnamed: JP1.59 (A2), JP2.59 (A2), JP3.59 (A2), JP4.59 (A2), JP5.59 (A2), JP6.59 (A2)
unnamed: JP1.57 (A3), JP2.57 (A3), JP3.57 (A3), JP4.57 (A3), JP5.57 (A3), JP6.57 (A3)
unnamed: JP1.55 (A4), JP2.55 (A4), JP3.55 (A4), JP4.55 (A4), JP5.55 (A4), JP6.55 (A4)
unnamed: JP1.53 (A5), JP2.53 (A5), JP3.53 (A5), JP4.53 (A5), JP5.53 (A5), JP6.53 (A5)
unnamed: JP1.49 (A6), JP2.49 (A6), JP3.49 (A6), JP4.49 (A6), JP5.49 (A6), JP6.49 (A6)
unnamed: JP1.47 (A7), JP2.47 (A7), JP3.47 (A7), JP4.47 (A7), JP5.47 (A7), JP6.47 (A7)
unnamed: JP1.45 (A8), JP2.45 (A8), JP3.45 (A8), JP4.45 (A8), JP5.45 (A8), JP6.45 (A8)
unnamed: JP1.43 (A9), JP2.43 (A9), JP3.43 (A9), JP4.43 (A9), JP5.43 (A9), JP6.43 (A9)
unnamed: JP1.41 (A10), JP2.41 (A10), JP3.41 (A10), JP4.41 (A10), JP5.41 (A10), JP6.41 (A10)
unnamed: JP1.39 (A11), JP2.39 (A11), JP3.39 (A11), JP4.39 (A11), JP5.39 (A11), JP6.39 (A11)
unnamed: JP1.37 (A12), JP2.37 (A12), JP3.37 (A12), JP4.37 (A12), JP5.37 (A12), JP6.37 (A12)
unnamed: JP1.35 (A13), JP2.35 (A13), JP3.35 (A13), JP4.35 (A13), JP5.35 (A13), JP6.35 (A13)
unnamed: JP1.33 (A14), JP2.33 (A14), JP3.33 (A14), JP4.33 (A14), JP5.33 (A14), JP6.33 (A14)
unnamed: LED1.A, R1.1
unnamed: C2.+, D1.C, IC1.1 (VI)
unnamed: MAX811.3 (!MR), S1.1 (S), S1.2 (S1)
VCC: C1.1, IC1.3 (VO), JP1.27 (VCC), JP2.27 (VCC), JP3.27 (VCC), JP4.27 (VCC), JP5.27 (VCC), JP6.27 (VCC), MAX811.4 (VCC), R1.2

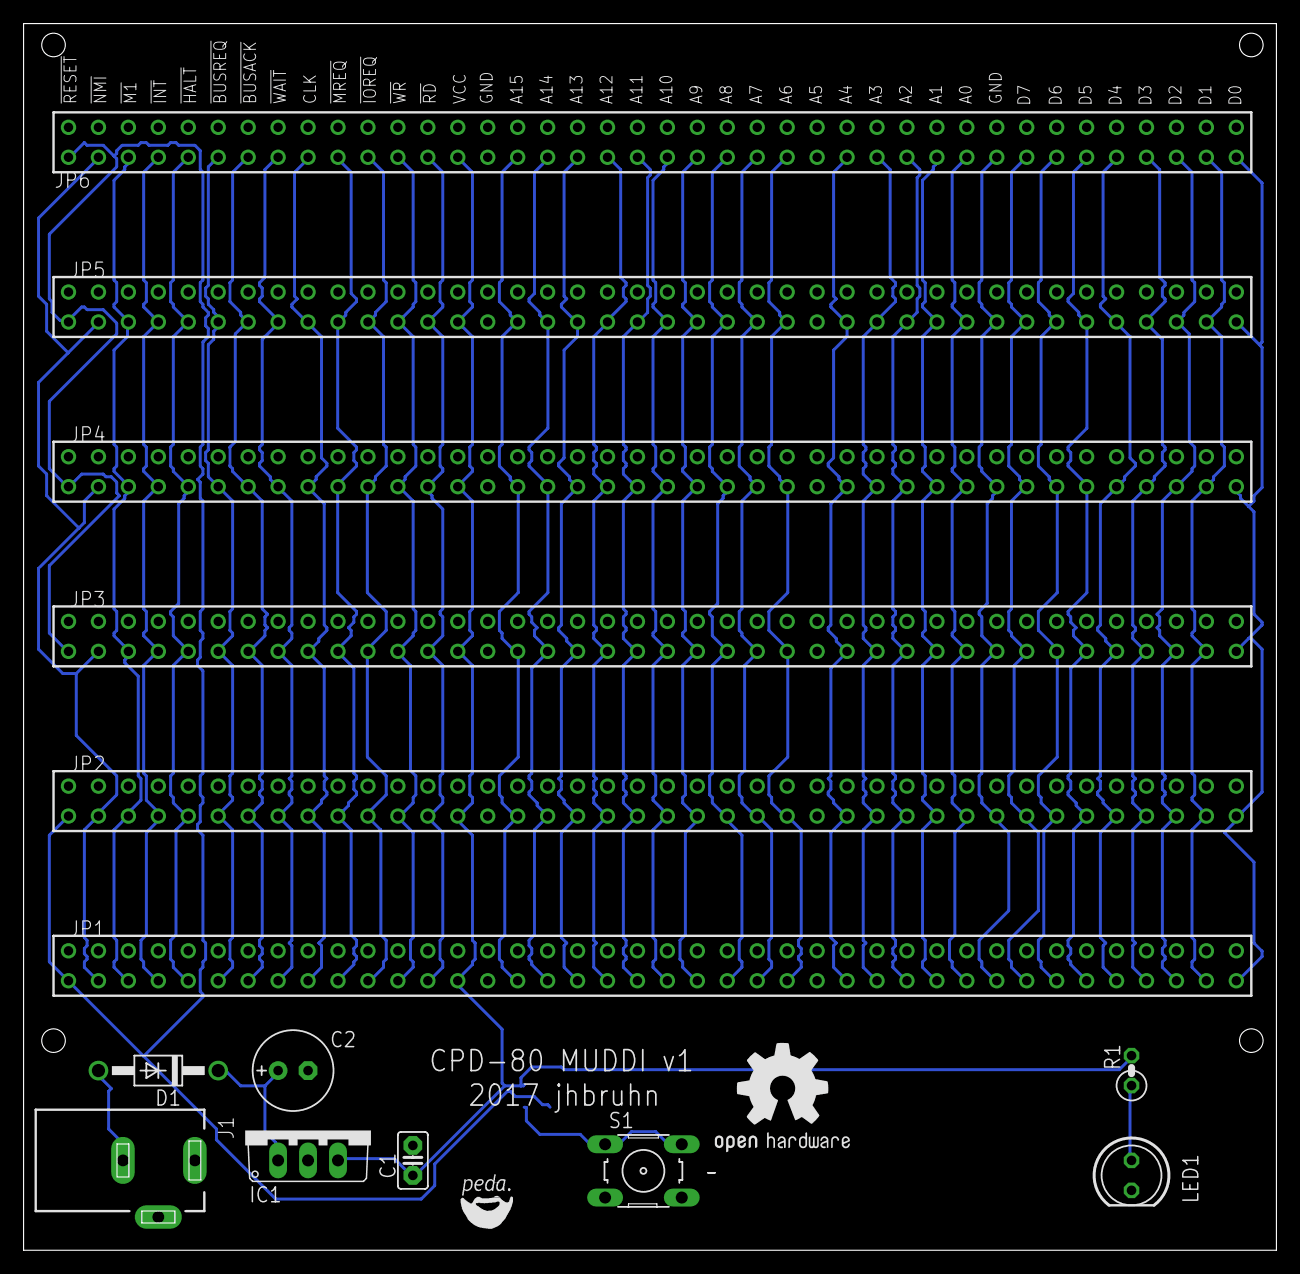
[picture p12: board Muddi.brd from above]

Board: 2 copper layers, 106.3 x 104.0 mm, 16 parts (1 on the bottom side), 43 nets.

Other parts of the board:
U$1: OSHW1

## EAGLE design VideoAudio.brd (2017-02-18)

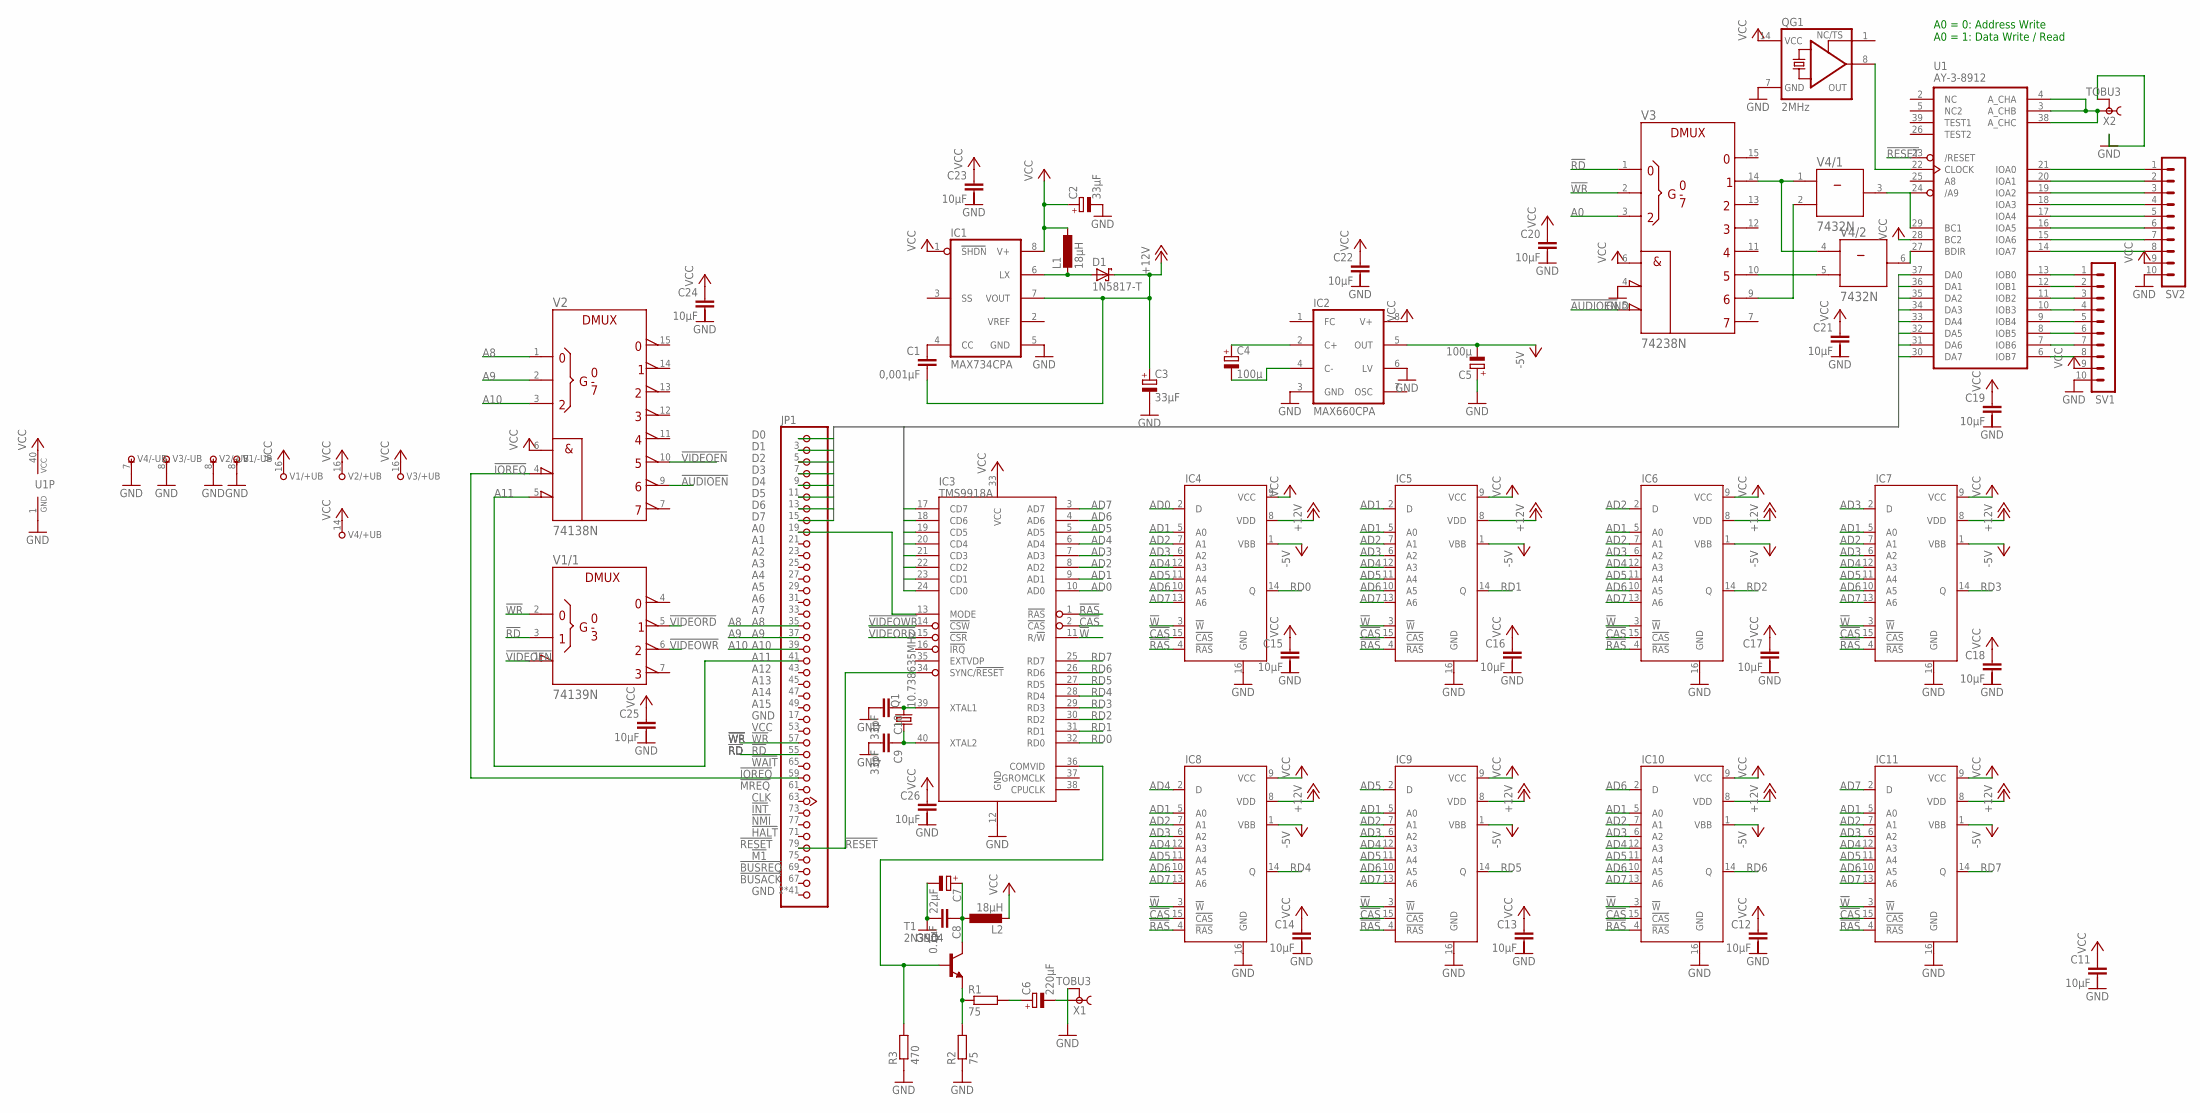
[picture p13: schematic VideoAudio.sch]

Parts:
C1: 0,001µF; C050-025X075
C2, C3: 33µF; E2,5-5
C4, C5: 100µ; E2,5-6
C6: 220µF; E2,5-5
C7: 22µF; E2,5-5
C8: 0.1µF; C025-030X050
C9, C10: 33pF; C025-030X050
C11, C12, C13, C14, C15, C16, C17, C18, C19, C20, C21, C22, C23, C24, C25, C26: 10µF; C050-025X075
D1: 1N5817-T; DO41-7.6
IC1: MAX734CPA; DIL08
IC2: MAX660CPA; DIL08
IC3: TMS9918A; DIP40
IC4, IC5, IC6, IC7, IC8, IC9, IC10, IC11: TMS4116; DIL16
JP1: JEANNECTOR/90; 2X25/90
L1, L2: 18µH; 0204/7
Q1: 10.738635MHz; HC49U70
QG1: 2MHz; DIL14S
R1, R2: 75; 0204V
R3: 470; 0204V
SV1, SV2: MA10-1
T1: 2N3904; TO92
U1: AY-3-8912; DIL40
V1: 74139N; DIL16
V2: 74138N; DIL16
V3: 74238N; DIL16
V4: 7432N; DIL14
X1, X2: TOBU3

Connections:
!AUDIOEN: V2.9 (Y6), V3.5 (!G2B)
!CAS: IC3.2 (!CAS), IC4.15 (!CAS), IC5.15 (!CAS), IC6.15 (!CAS), IC7.15 (!CAS), IC8.15 (!CAS), IC9.15 (!CAS), IC10.15 (!CAS), IC11.15 (!CAS)
!IOREQ: JP1.59 (!IOREQ), V2.4 (!G2A)
!RAS: IC3.1 (!RAS), IC4.4 (!RAS), IC5.4 (!RAS), IC6.4 (!RAS), IC7.4 (!RAS), IC8.4 (!RAS), IC9.4 (!RAS), IC10.4 (!RAS), IC11.4 (!RAS)
!RD: JP1.55 (!RD), V1.3 (B), V3.1 (A)
!RESET: IC3.34 (SYNC/!RESET), JP1.79 (!RESET), U1.23 (/RESET)
!VIDEOEN: V1.1 (!G), V2.10 (Y5)
!VIDEORD: IC3.15 (!CSR), V1.5 (Y1)
!VIDEOWR: IC3.14 (!CSW), V1.6 (Y2)
!W: IC3.11 (R/!W), IC4.3 (!W), IC5.3 (!W), IC6.3 (!W), IC7.3 (!W), IC8.3 (!W), IC9.3 (!W), IC10.3 (!W), IC11.3 (!W)
!WR: JP1.57 (!WR), V1.2 (A), V3.2 (B)
+12V: C1.2, C3.+, D1.C, IC1.7 (VOUT), IC4.8 (VDD), IC5.8 (VDD), IC6.8 (VDD), IC7.8 (VDD), IC8.8 (VDD), IC9.8 (VDD), IC10.8 (VDD), IC11.8 (VDD)
-5V: C5.-, IC2.5 (OUT), IC4.1 (VBB), IC5.1 (VBB), IC6.1 (VBB), IC7.1 (VBB), IC8.1 (VBB), IC9.1 (VBB), IC10.1 (VBB), IC11.1 (VBB)
A0: V3.3 (C)
A8: JP1.35 (A8), V2.1 (A)
A9: JP1.37 (A9), V2.2 (B)
A10: JP1.39 (A10), V2.3 (C)
A11: JP1.41 (A11), V2.5 (!G2B)
AD0: IC3.10 (AD0), IC4.2 (D)
AD1: IC3.9 (AD1), IC4.5 (A0), IC5.2 (D), IC5.5 (A0), IC6.5 (A0), IC7.5 (A0), IC8.5 (A0), IC9.5 (A0), IC10.5 (A0), IC11.5 (A0)
AD2: IC3.8 (AD2), IC4.7 (A1), IC5.7 (A1), IC6.2 (D), IC6.7 (A1), IC7.7 (A1), IC8.7 (A1), IC9.7 (A1), IC10.7 (A1), IC11.7 (A1)
AD3: IC3.7 (AD3), IC4.6 (A2), IC5.6 (A2), IC6.6 (A2), IC7.2 (D), IC7.6 (A2), IC8.6 (A2), IC9.6 (A2), IC10.6 (A2), IC11.6 (A2)
AD4: IC3.6 (AD4), IC4.12 (A3), IC5.12 (A3), IC6.12 (A3), IC7.12 (A3), IC8.2 (D), IC8.12 (A3), IC9.12 (A3), IC10.12 (A3), IC11.12 (A3)
AD5: IC3.5 (AD5), IC4.11 (A4), IC5.11 (A4), IC6.11 (A4), IC7.11 (A4), IC8.11 (A4), IC9.2 (D), IC9.11 (A4), IC10.11 (A4), IC11.11 (A4)
AD6: IC3.4 (AD6), IC4.10 (A5), IC5.10 (A5), IC6.10 (A5), IC7.10 (A5), IC8.10 (A5), IC9.10 (A5), IC10.2 (D), IC10.10 (A5), IC11.10 (A5)
AD7: IC3.3 (AD7), IC4.13 (A6), IC5.13 (A6), IC6.13 (A6), IC7.13 (A6), IC8.13 (A6), IC9.13 (A6), IC10.13 (A6), IC11.2 (D), IC11.13 (A6)
D0: IC3.24 (CD0), JP1.1 (D0), U1.37 (DA0)
D1: IC3.23 (CD1), JP1.3 (D1), U1.36 (DA1)
D2: IC3.22 (CD2), JP1.5 (D2), U1.35 (DA2)
D3: IC3.21 (CD3), JP1.7 (D3), U1.34 (DA3)
D4: IC3.20 (CD4), JP1.9 (D4), U1.33 (DA4)
D5: IC3.19 (CD5), JP1.11 (D5), U1.32 (DA5)
D6: IC3.18 (CD6), JP1.13 (D6), U1.31 (DA6)
D7: IC3.17 (CD7), JP1.15 (D7), U1.30 (DA7)
GND: C2.-, C3.-, C5.+, C7.-, C8.2, C9.2, C10.2, IC1.5 (GND), IC2.3 (GND), IC2.6 (LV), IC3.12 (GND), IC4.16 (GND), IC5.16 (GND), IC6.16 (GND), IC7.16 (GND), IC8.16 (GND), IC9.16 (GND), IC10.16 (GND), IC11.16 (GND), JP1.2 (GND), JP1.4 (GND), JP1.6 (GND), JP1.8 (GND), JP1.10 (GND), JP1.12 (GND), JP1.14 (GND), JP1.16 (GND), JP1.17 (GND), JP1.18 (GND), JP1.20 (GND), JP1.22 (GND), JP1.24 (GND), JP1.26 (GND), JP1.28 (GND), JP1.30 (GND), JP1.32 (GND), JP1.34 (GND), JP1.36 (GND), JP1.38 (GND), JP1.40 (GND), JP1.42 (GND), JP1.44 (GND), JP1.46 (GND), JP1.48 (GND), JP1.50 (GND), JP1.51 (GND), JP1.52 (GND), JP1.54 (GND), JP1.56 (GND), JP1.58 (GND), JP1.60 (GND), JP1.62 (GND), JP1.64 (GND), JP1.66 (GND), JP1.68 (GND), JP1.70 (GND), JP1.72 (GND), JP1.74 (GND), JP1.76 (GND), JP1.78 (GND), JP1.80 (GND), QG1.7 (GND), R2.1, R3.1, SV1.10, SV2.10, U1.1 (GND), V1.8 (-UB), V2.8 (-UB), V3.4 (!G2A), V3.8 (-UB), V4.7 (-UB), X1.2, X1.2@1 (2), X1.2@2 (2), X2.2, X2.2@1 (2), X2.2@2 (2)
unnamed: C4.-, IC2.4 (C-)
unnamed: C4.+, IC2.2 (C+)
unnamed: D1.A, IC1.6 (LX), L1.2
unnamed: C1.1, IC1.4 (CC)
unnamed: IC3.13 (MODE), JP1.19 (A0)
unnamed: U1.3 (A_CHB), U1.4 (A_CHA), U1.38 (A_CHC), X2.1
unnamed: C6.-, X1.1
unnamed: C6.+, R1.2
unnamed: R1.1, R2.2, T1.3 (E)
unnamed: IC3.36 (COMVID), R3.2, T1.2 (B)
unnamed: V3.9 (Y6), V4.2 (B)
unnamed: C7.+, C8.1, L2.1, T1.1 (C)
unnamed: C10.1, IC3.39 (XTAL1), Q1.2
unnamed: C9.1, IC3.40 (XTAL2), Q1.1
unnamed: U1.29 (BC1), V4.3 (Y)
unnamed: V3.14 (Y1), V4.1 (A), V4.4 (A)
unnamed: U1.27 (BDIR), V4.6 (Y)
unnamed: V3.10 (Y5), V4.5 (B)
unnamed: SV1.1, U1.13 (IOB0)
unnamed: SV1.2, U1.12 (IOB1)
unnamed: SV1.3, U1.11 (IOB2)
unnamed: SV1.4, U1.10 (IOB3)
unnamed: SV1.5, U1.9 (IOB4)
unnamed: SV1.6, U1.8 (IOB5)
unnamed: SV1.7, U1.7 (IOB6)
unnamed: SV1.8, U1.6 (IOB7)
unnamed: QG1.8 (OUT), U1.22 (CLOCK)
unnamed: SV2.1, U1.21 (IOA0)
unnamed: SV2.2, U1.20 (IOA1)
unnamed: SV2.3, U1.19 (IOA2)
unnamed: SV2.4, U1.18 (IOA3)
unnamed: SV2.5, U1.17 (IOA4)
unnamed: SV2.6, U1.16 (IOA5)
unnamed: SV2.7, U1.15 (IOA6)
unnamed: SV2.8, U1.14 (IOA7)
RD0: IC3.32 (RD0), IC4.14 (Q)
RD1: IC3.31 (RD1), IC5.14 (Q)
RD2: IC3.30 (RD2), IC6.14 (Q)
RD3: IC3.29 (RD3), IC7.14 (Q)
RD4: IC3.28 (RD4), IC8.14 (Q)
RD5: IC3.27 (RD5), IC9.14 (Q)
RD6: IC3.26 (RD6), IC10.14 (Q)
RD7: IC3.25 (RD7), IC11.14 (Q)
VCC: C2.+, C11.1, C12.1, C13.1, C14.1, C15.1, C16.1, C17.1, C18.1, C19.1, C20.1, C21.1, C22.1, C23.1, C24.1, C25.1, C26.1, IC1.1 (SHDN), IC1.8 (V+), IC2.8 (V+), IC3.33 (VCC), IC4.9 (VCC), IC5.9 (VCC), IC6.9 (VCC), IC7.9 (VCC), IC8.9 (VCC), IC9.9 (VCC), IC10.9 (VCC), IC11.9 (VCC), JP1.53 (VCC), L1.1, L2.2, QG1.14 (VCC), SV1.9, SV2.9, U1.28 (BC2), U1.40 (VCC), V1.16 (+UB), V2.6 (G1), V2.16 (+UB), V3.6 (G1), V3.16 (+UB), V4.14 (+UB)

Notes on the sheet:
A0 = 0: Address Write A0 = 1: Data Write / Read

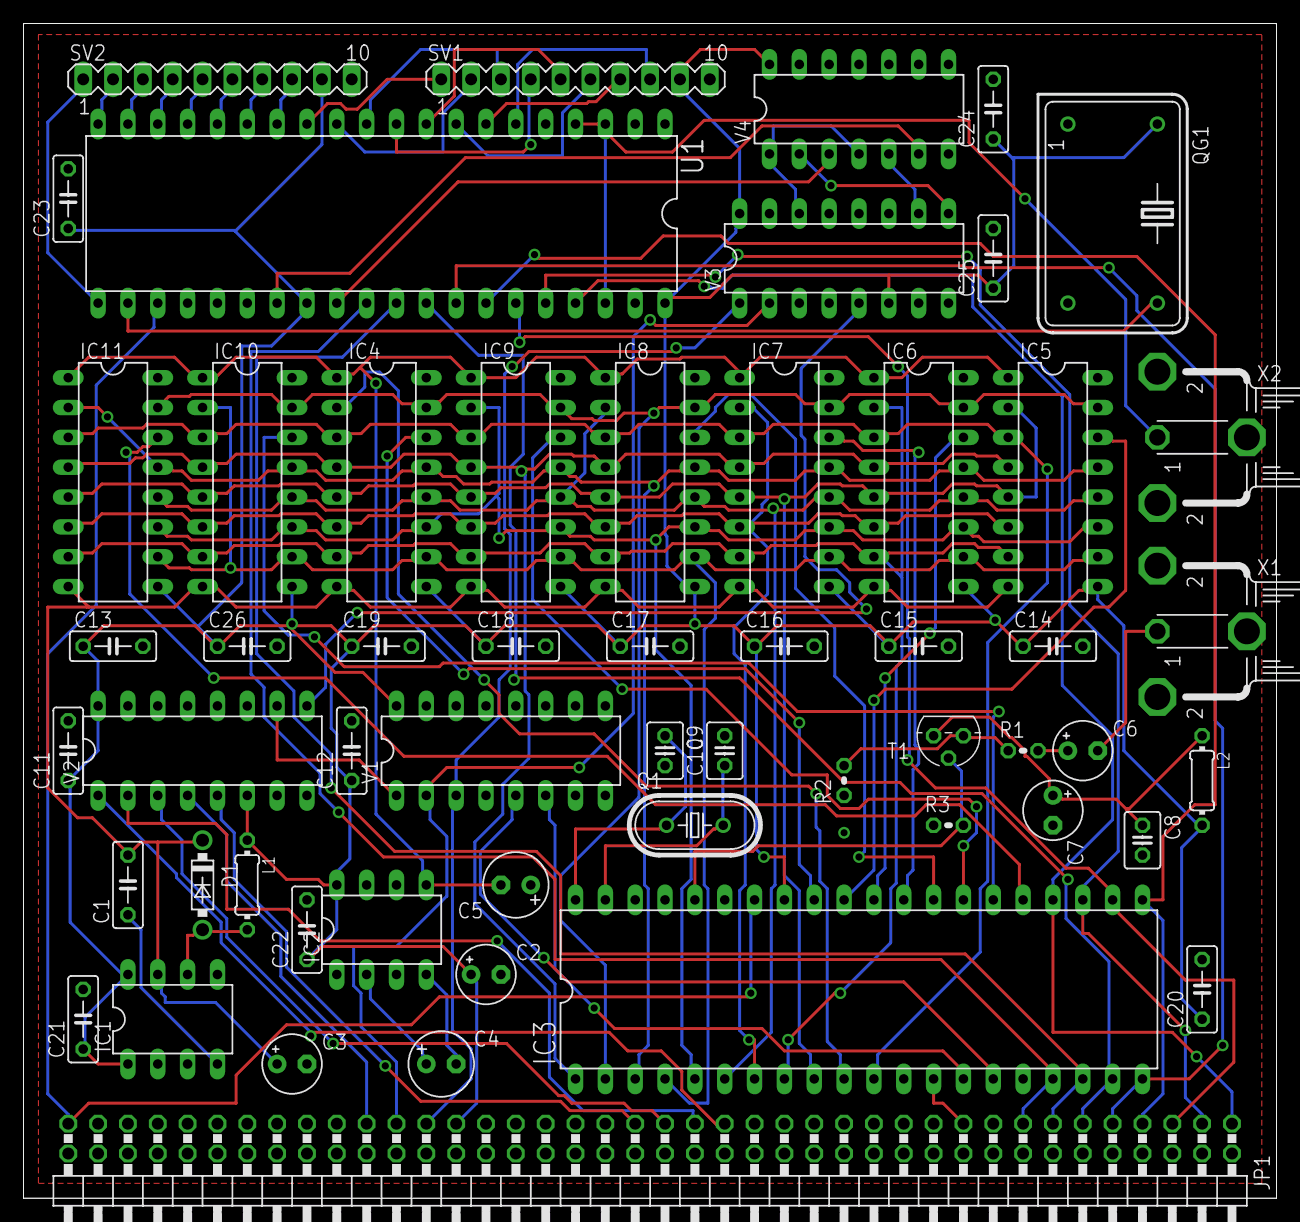
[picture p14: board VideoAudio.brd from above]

Board: 2 copper layers, 106.7 x 100.0 mm, 56 parts (0 on the bottom side), 78 nets.

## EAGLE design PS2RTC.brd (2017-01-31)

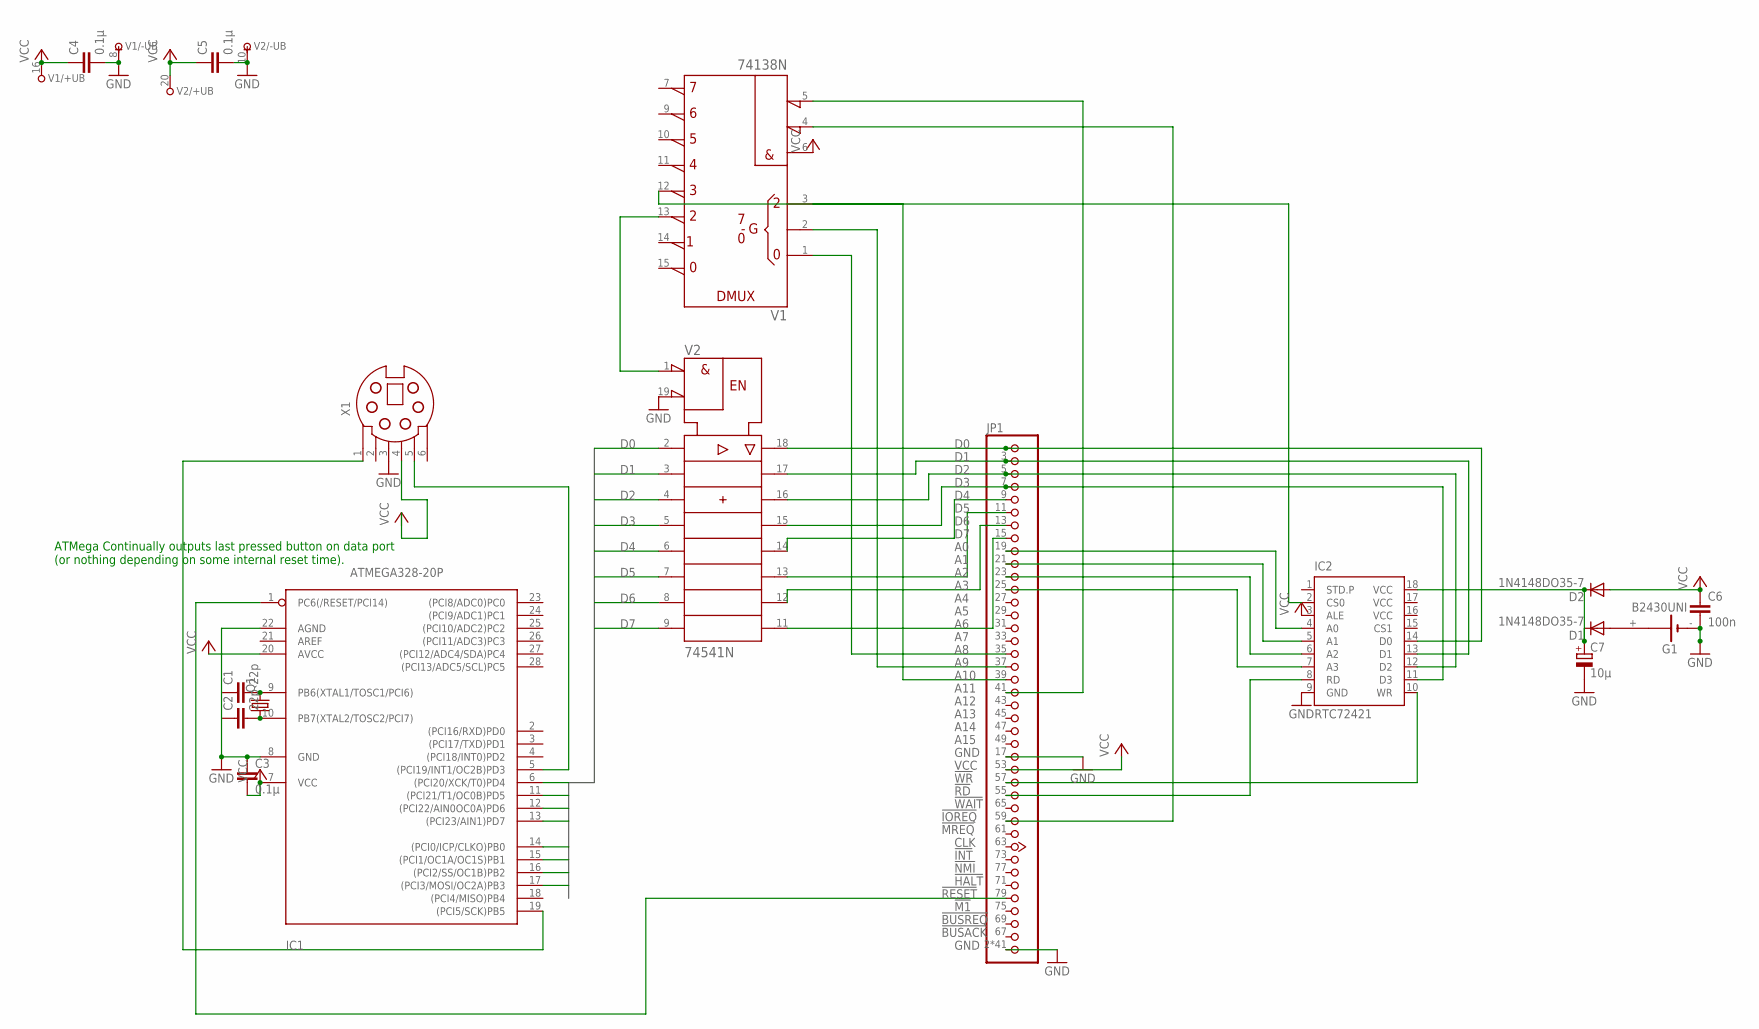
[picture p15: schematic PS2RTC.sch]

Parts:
C1, C2: 22p; C5B3
C3, C4, C5: 0.1µ; C5B3
C6: 100n; C2.5-2
C7: 10µ; E2-4
D1, D2: 1N4148DO35-7; DO35-7
G1: B2430UNI
IC1: ATMEGA328-20P; DIL28-3
IC2: RTC72421; DIL18
JP1: JEANNECTOR/90; 2X25/90
Q1: CRYSTALHC49S; HC49/S
V1: 74138N; DIL16
V2: 74541N; DIL20
X1: MDSSV-F06; SSV-BC06

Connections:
D0: IC1.6 ((PCI20/XCK/T0)PD4), V2.2 (A1)
D1: IC1.11 ((PCI21/T1/OC0B)PD5), V2.3 (A2)
D2: IC1.12 ((PCI22/AIN0OC0A)PD6), V2.4 (A3)
D3: IC1.13 ((PCI23/AIN1)PD7), V2.5 (A4)
D4: IC1.14 ((PCI0/ICP/CLKO)PB0), V2.6 (A5)
D5: IC1.15 ((PCI1/OC1A/OC1S)PB1), V2.7 (A6)
D6: IC1.16 ((PCI2/SS/OC1B)PB2), V2.8 (A7)
D7: IC1.17 ((PCI3/MOSI/OC2A)PB3), V2.9 (A8)
GND: C3.1, C4.2, C5.2, C6.2, C7.-, G1.-, IC1.8 (GND), IC1.22 (AGND), IC2.9 (GND), JP1.2 (GND), JP1.4 (GND), JP1.6 (GND), JP1.8 (GND), JP1.10 (GND), JP1.12 (GND), JP1.14 (GND), JP1.16 (GND), JP1.17 (GND), JP1.18 (GND), JP1.20 (GND), JP1.22 (GND), JP1.24 (GND), JP1.26 (GND), JP1.28 (GND), JP1.30 (GND), JP1.32 (GND), JP1.34 (GND), JP1.36 (GND), JP1.38 (GND), JP1.40 (GND), JP1.42 (GND), JP1.44 (GND), JP1.46 (GND), JP1.48 (GND), JP1.50 (GND), JP1.51 (GND), JP1.52 (GND), JP1.54 (GND), JP1.56 (GND), JP1.58 (GND), JP1.60 (GND), JP1.62 (GND), JP1.64 (GND), JP1.66 (GND), JP1.68 (GND), JP1.70 (GND), JP1.72 (GND), JP1.74 (GND), JP1.76 (GND), JP1.78 (GND), JP1.80 (GND), V1.8 (-UB), V2.10 (-UB), V2.19 (!G2), X1.3
unnamed: JP1.35 (A8), V1.1 (A)
unnamed: JP1.37 (A9), V1.2 (B)
unnamed: JP1.39 (A10), V1.3 (C)
unnamed: IC1.5 ((PCI19/INT1/OC2B)PD3), X1.5
unnamed: V1.13 (Y2), V2.1 (!G1)
unnamed: IC1.19 ((PCI5/SCK)PB5), X1.1
unnamed: JP1.59 (!IOREQ), V1.4 (!G2A)
unnamed: JP1.41 (A11), V1.5 (!G2B)
unnamed: IC2.14 (D0), JP1.1 (D0), V2.18 (Y1)
unnamed: IC2.13 (D1), JP1.3 (D1), V2.17 (Y2)
unnamed: IC2.12 (D2), JP1.5 (D2), V2.16 (Y3)
unnamed: IC2.11 (D3), JP1.7 (D3), V2.15 (Y4)
unnamed: JP1.9 (D4), V2.14 (Y5)
unnamed: JP1.11 (D5), V2.13 (Y6)
unnamed: JP1.13 (D6), V2.12 (Y7)
unnamed: JP1.15 (D7), V2.11 (Y8)
unnamed: IC1.1 (PC6(/RESET/PCI14)), JP1.79 (!RESET)
unnamed: C1.2, IC1.9 (PB6(XTAL1/TOSC1/PCI6)), Q1.2
unnamed: C2.2, IC1.10 (PB7(XTAL2/TOSC2/PCI7)), Q1.1
unnamed: D1.A, G1.+
unnamed: IC2.4 (A0), JP1.19 (A0)
unnamed: IC2.5 (A1), JP1.21 (A1)
unnamed: C7.+, D1.C, D2.C, IC2.18 (VCC)
unnamed: IC2.6 (A2), JP1.23 (A2)
unnamed: IC2.7 (A3), JP1.25 (A3)
unnamed: IC2.8 (RD), JP1.55 (!RD)
unnamed: IC2.10 (WR), JP1.57 (!WR)
unnamed: IC2.2 (CS0), V1.12 (Y3)
VCC: C3.2, C4.1, C5.1, C6.1, D2.A, IC1.7 (VCC), IC1.20 (AVCC), IC2.3 (ALE), IC2.16 (VCC), IC2.17 (VCC), JP1.53 (VCC), V1.6 (G1), V1.16 (+UB), V2.20 (+UB), X1.4

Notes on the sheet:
ATMega Continually outputs last pressed button on data port (or nothing depending on some internal reset time).

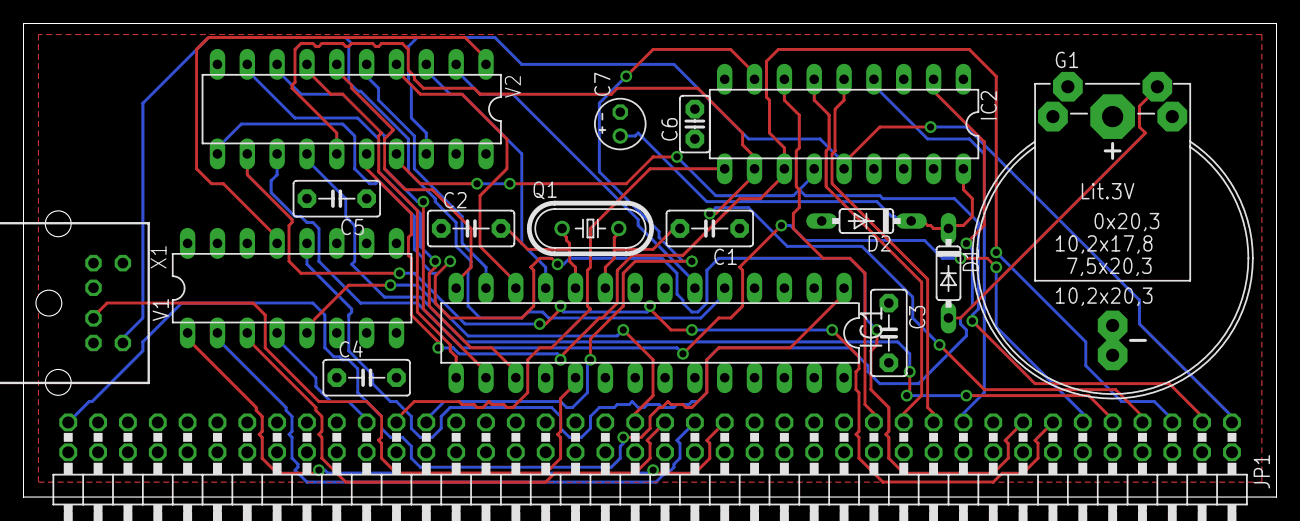
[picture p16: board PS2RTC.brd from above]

Board: 2 copper layers, 106.7 x 40.3 mm, 17 parts (0 on the bottom side), 38 nets.

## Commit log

2017-01-22 Add Readme, Add Wait line for IO
    [Main-Board.brd, Main-Board.sch]
2017-01-22 Add Image of Circuit
2017-01-23 Start Splitting into multiple boards
    [CPU.sch, Main-Board.brd, Memory.brd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]
2017-01-24 Connect ROM WriteEnable so we can rewrite rom from the CPU
    [Memory.brd, Memory.sch]
2017-01-24 Move away Serial CF
    [CPU.brd, CPU.sch, Muddi.brd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]
2017-01-24 Finish Modularization
    [CPU.sch, Memory.brd, Memory.sch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]
2017-01-25 Update names and font
    [CPU.brd, Memory.brd, Muddi.brd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]
2017-01-25 Add Resistor Value
    [Muddi.brd, Muddi.sch]
2017-01-25 Add Interrupt connection for 16550
    [SerialCF.brd, SerialCF.sch]
2017-01-25 Change Memoryboard
    [Memory.brd, Memory.sch]
2017-01-25 Fix MUDDI. Change values to mm.
    [CPU.brd, Memory.brd, Muddi.brd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]
2017-01-26 Add Decoupling Capacitors.
    [CPU.brd, CPU.sch, Memory.brd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]
2017-01-26 Change addressbus to allow more devices on it.
    [SerialCF.brd, SerialCF.sch]
2017-01-26 Add Ground Rail to JEANNECTOR
    [CPU.brd, CPU.sch, Memory.brd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]
2017-01-27 Make Top Plane a VCC Plane instead of Ground, add Holes
    [CPU.brd, Memory.brd, Muddi.brd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]
2017-01-27 Remove Old Circuit Diagram
2017-01-27 Add Schematic Pictures
2017-01-28 Correctly wire the Enable on SerialCF 74138
    [Muddi.brd]
2017-01-28 Update SerialCF Picture
    [SerialCF.brd, SerialCF.sch]
2017-01-28 Add PullUp to reset of cpu
    [CPU.brd, CPU.sch]
2017-01-28 Use MAX811 for Reset. Add Power Capacitors.
    [Muddi.brd, Muddi.sch]
2017-01-28 Fix Memory Mapping inversely. Move Text on Muddi
    [Memory.brd, Memory.sch, Muddi.brd]
2017-01-28 Use upper Bits to Address IO devices.
    [SerialCF.brd, SerialCF.sch]
2017-01-28 Update Circuit pictures
2017-01-28 Fix memory mapping issues
    [Memory.brd, Memory.sch]
2017-01-28 Use LS version for serialCF
    [SerialCF.brd, SerialCF.sch]
2017-01-28 Add PullUps to CPU Board
    [CPU.brd, CPU.sch]
2017-01-28 Update Muddi Spacing
    [Muddi.brd]
2017-01-28 Add more mounting holes to muddi
    [Muddi.brd]
2017-01-28 Remove old gerber files
2017-01-30 Update SerialCF
    [SerialCF.brd, SerialCF.sch]
2017-01-30 Add Experimental PS2 Board.
    [PS2.brd, PS2.sch]
2017-01-30 Reposition Capacitor
    [PS2.brd]
2017-01-30 Extend GND Trace
    [PS2.brd]
2017-01-31 Add RTC to PS2 Board
    [PS2.brd, PS2.sch, PS2RTC.brd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]
2017-02-01 Fix incorrectly connected diode
    [Muddi.brd, Muddi.sch]
2017-02-01 Added memory ram banking to the memory board
    [Memory.brd, Memory.sch]
2017-02-01 Add Memory Bank Switch documentation
2017-02-01 Fix Missing VCC and GND Connections
    [Memory.brd, Memory.sch]
2017-02-02 Added Oscillator to SerialCF Board. And more Serial Pins
    [SerialCF.brd, SerialCF.sch]
2017-02-02 Update Memory
    [Memory.brd]
2017-02-02 Update Versions of Memory and SerialCF
    [Memory.brd, SerialCF.brd]
2017-02-02 Rearrange Text on Memory Board
    [Memory.brd]
2017-02-02 Rearrange Text on SerialCF Board
    [SerialCF.brd]
2017-02-02 Add more Texts
    [Muddi.brd, Muddi.sch, SerialCF.brd]
2017-02-13 Restructure CPU Schematic
    [CPU.brd, CPU.sch]
2017-02-17 Beginn of VideoAudio Board
    [VideoAudio.brd, VideoAudio.sch]
2017-02-17 Fix Routing Issues with PowerPlanes
    [CPU.brd, Memory.brd, SerialCF.brd]
2017-02-17 Add Audio and Video to videoboard, not yet ready
    [VideoAudio.brd, VideoAudio.sch]
2017-02-18 Route Audio/Video Board
    [VideoAudio.brd]
2017-03-03 Fix stupid VCC/GND mistakes on Address decoder
    [Muddi.brd, Muddi.sch, SerialCF.brd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]
2017-08-14 Add missing wires
    [CPU.brd, CPU.sch]
2017-08-17 Add pullup
    [Memory.brd, Memory.sch, SerialCF.brd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]
